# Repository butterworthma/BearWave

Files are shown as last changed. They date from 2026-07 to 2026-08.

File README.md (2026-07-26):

# BearWave

This repository collects the implementation artifacts for the BearWave system.

## Contents

- `control-node/` - Raspberry Pi control-node dashboard, JS8Call/SparkSDR/QSSTV helper configuration, image watcher, startup services, and setup documentation.
- `remote-node/` - Raspberry Pi Zero remote-node application, boot-cycle service, SSTV capture/encode/transmit scripts, ESP32 supervisor code, and the remote-node hardware design material.

The paper source has deliberately been moved out to `BearWave_Papers` so this repository can remain focused on the deployable system code, hardware files, and operator setup notes.

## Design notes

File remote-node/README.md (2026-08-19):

# BearWave Remote Node

This repository contains the current BearWave remote-node software and setup material.

The remote node is the low-power Raspberry Pi and ESP32/Heltec field unit. The ESP32 supervises power, trap inputs, GPS/RTC time, battery state, and deep sleep. The Raspberry Pi boots only during a wake cycle, sends BearWave messages through JS8Call, optionally sends an SSTV image after an acknowledged alarm, asks the ESP32 to shut it down, and then the ESP32 removes the Pi/radio power rail.

The reliable part of BearWave remains the JS8Call alarm and ACK path. The SSTV image is an optional best-effort extension. A missed or undecoded image must not be treated as a missed alarm.

## Repository Layout

```text
remote-pi/
  app/                 Current Raspberry Pi Python application
  scripts/             Boot-cycle, ESP32 UART, JS8Call, and SSTV TX scripts
  systemd/             bearwave-cycle.service template
  requirements.txt     Python packages for the Pi virtual environment

esp32-supervisor/
  BearWave_ESP32_Remote_Node_Supervisor/
    BearWave_ESP32_Remote_Node_Supervisor.ino
  README.md

docs/
  live-pi-setup-check.md
```

## Live Deployment Model

Tested live path on the remote Pi:

```text
/home/mark/bearwave
```

Main live systemd service:

```text
/etc/systemd/system/bearwave-cycle.service
```

Main service target:

```text
graphical.target
```

The service runs as root because it sets system time, launches JS8Call for the `mark` user, communicates with `/dev/serial0`, and halts the Pi at the end of the wake cycle. If a monitor is connected, JS8Call uses the real desktop display; when the field node is headless, the boot script starts a small Xvfb virtual display so JS8Call can still run unattended.

## Wake Cycle Summary

1. ESP32 wakes from timer or event.
2. ESP32 checks the latched 5 V and 12 V rail feedback lines and forces both rails OFF so each cycle starts from a known state.
3. ESP32 refreshes GPS/RTC state, then pulses the 5 V latch on and pulses the 12 V latch on.
4. Raspberry Pi boots into the graphical target.
5. `bearwave-cycle.service` runs `remote-pi/scripts/bearwave_boot_cycle.sh`.
6. The boot script waits for the ESP32 UART at `/dev/serial0`.
7. The boot script waits for the QDX CAT/audio device at `/dev/ttyACM0` before launching JS8Call.
8. The Pi asks the ESP32 for UTC time with `TIME?`.
9. The Pi starts JS8Call on the physical display, or under Xvfb when headless.
10. The Pi waits for the JS8Call TCP API on `127.0.0.1:2442`, then sets JS8Call to 7.078 MHz.
11. The Python app in `remote-pi/app/` sends heartbeat, trap alarm, low-battery, or pending critical messages.
12. The Pi waits for the control-node ACK.
13. If an alarm is acknowledged and SSTV is enabled, the Pi captures, encodes, and transmits one SSTV image.
14. The Pi sends `EVENT_ACKED,<type>` for delivered critical events.
15. The Pi sends `SHUTDOWN` to the ESP32 and halts Linux.
16. ESP32 waits for Linux shutdown, pulses the 12 V latch off, pulses the 5 V latch off, turns the OLED off, and sleeps until the next wake.

## Current SSTV Extension

The SSTV extension is intentionally thin and isolated from the alarm path:

- `remote-pi/app/sstv_image.py` handles image capture, resize/prepare, SSTV WAV encoding, optional JS8Call stop, and transmit command orchestration.
- `remote-pi/scripts/sstv_transmit_qdx.sh` keys the QDX with `rigctl`, plays the generated WAV with `aplay`, and always attempts to release PTT on exit.
- `remote-pi/scripts/bearwave_boot_cycle.sh` passes SSTV configuration into the Python app through environment variables.

Current live defaults from the Pi:

```bash
BEARWAVE_SSTV_ENABLED=1
BEARWAVE_SSTV_DRY_RUN=0
BEARWAVE_SSTV_REPEAT_COUNT=1
BEARWAVE_SSTV_MODE=ScottieS1
BEARWAVE_SSTV_TX_GAIN=1.0
BEARWAVE_SSTV_WORK_DIR=/home/mark/bearwave/sstv
```

Image capture:

```bash
rpicam-still -o {image} --width 1280 --height 960 --timeout 1000 --nopreview
```

Encoding:

```bash
/home/mark/bearwave/.venv/bin/python -m pysstv --mode {mode} {prepared} {wav}
```

Transmit:

```bash
/home/mark/bearwave/scripts/sstv_transmit_qdx.sh {wav}
```

The control node receives this image using QSSTV and displays any decoded image as a clickable thumbnail. Image reception is not guaranteed.

## Raspberry Pi Install

Start from Raspberry Pi OS with a desktop environment. The live node uses user `mark`.

Install system packages:

```bash
sudo apt update
sudo apt install -y git python3 python3-venv python3-pip js8call rpicam-apps ffmpeg alsa-utils libhamlib-utils lxterminal xvfb
```

Clone the repository:

```bash
cd /home/mark
git clone https://github.com/butterworthma/BearWave.git BearWave
mkdir -p /home/mark/bearwave
```

Install the active remote Pi files:

```bash
cp -r /home/mark/BearWave/remote-node/remote-pi/app /home/mark/bearwave/
cp -r /home/mark/BearWave/remote-node/remote-pi/scripts /home/mark/bearwave/
mkdir -p /home/mark/bearwave/logs /home/mark/bearwave/state /home/mark/bearwave/sstv
chmod +x /home/mark/bearwave/scripts/*.sh
chmod +x /home/mark/bearwave/scripts/*.py
```

Create the Python virtual environment:

```bash
cd /home/mark/bearwave
python3 -m venv .venv
. .venv/bin/activate
pip install --upgrade pip
pip install -r /home/mark/BearWave/remote-node/remote-pi/requirements.txt
```

Install the systemd service:

```bash
sudo cp /home/mark/BearWave/remote-node/remote-pi/systemd/bearwave-cycle.service /etc/systemd/system/bearwave-cycle.service
sudo systemctl daemon-reload
sudo systemctl enable bearwave-cycle.service
```

Manual start for bench testing:

```bash
sudo systemctl start bearwave-cycle.service
```

Check status and logs:

```bash
systemctl status bearwave-cycle.service --no-pager -l
journalctl -u bearwave-cycle.service -f
tail -f /home/mark/bearwave/logs/boot_cycle.log
```

## JS8Call Setup

Before unattended testing, start JS8Call manually once and confirm:

- Station callsign is configured.
- TCP API and TCP request acceptance are enabled on `127.0.0.1:2442`.
- The QDX/radio audio device is selected.
- CAT/PTT works from JS8Call.
- The saved desktop profile starts correctly from `/usr/share/applications/js8call.desktop`.

The boot script launches JS8Call using the desktop launcher when a physical display is available, because that path reproduced the saved audio/radio profile reliably during bench testing. If no monitor is connected, it starts `Xvfb` on display `:99` and launches `/usr/bin/js8call` directly in that virtual display. This keeps the Pi Zero 2 W remote node usable as a fully headless field unit.

## QDX SSTV Transmit Setup

Confirm QDX audio and CAT/PTT:

```bash
aplay -l
rigctl -m 2052 -r /dev/ttyACM0 -s 4800 T 0
```

Live tested playback device:

```text
plughw:CARD=Transceiver,DEV=0
```

The transmit helper defaults are:

```bash
BEARWAVE_SSTV_RIG_MODEL=2052
BEARWAVE_SSTV_RIG_DEVICE=/dev/ttyACM0
BEARWAVE_SSTV_RIG_SPEED=4800
BEARWAVE_SSTV_AUDIO_DEVICE=plughw:CARD=Transceiver,DEV=0
BEARWAVE_SSTV_PTT_SETTLE_S=0.5
BEARWAVE_SSTV_TX_GAIN=1.0
```

## ESP32 Supervisor

The ESP32 firmware is stored as a normal Arduino sketch folder:

```text
esp32-supervisor/BearWave_ESP32_Remote_Node_Supervisor/BearWave_ESP32_Remote_Node_Supervisor.ino
```

It controls:

- 5 V Pi rail through the PCB V2 latch pulse on GPIO 7.
- 12 V QDX/radio/ATU rail through the PCB V2 latch pulse on GPIO 38.
- Active-low 5 V and 12 V rail feedback on GPIO 47 and GPIO 48.
- Trap inputs.
- Battery sensing.
- GPS/RTC time.
- OLED diagnostics.
- Pi UART command interface.
- Deep sleep and GPIO hold.

See `esp32-supervisor/README.md` for the pin map, UART protocol, OLED diagnostics, and sleep/wake sequence.

## Important Design Notes

- The ESP32 is the hardware authority.
- The Pi is the radio/application authority.
- The JS8Call alarm message and ACK are the reliable low-power messaging mechanism.
- SSTV is secondary evidence after an alarm and is best effort.
- Failed critical messages are preserved by the Pi app and retried on later boots.
- Routine heartbeats are not stored for retry.
- The control node must not assume an image will always be received.

## Validation Checklist

On the remote Pi:

```bash
test -x /home/mark/bearwave/scripts/bearwave_boot_cycle.sh
test -x /home/mark/bearwave/scripts/sstv_transmit_qdx.sh
/home/mark/bearwave/.venv/bin/python -m py_compile /home/mark/bearwave/app/*.py
/home/mark/bearwave/.venv/bin/python - <<'PY'
import serial
import PIL
import pysstv
print("remote Python dependencies OK")
PY
command -v rpicam-still
command -v aplay
command -v ffmpeg
command -v rigctl
command -v js8call
command -v Xvfb
```

Live check on 2026-07-26 found:

- `rpicam-still` present.
- `aplay` present.
- `ffmpeg` present.
- `js8call` present.
- Python modules `serial`, `PIL`, and `pysstv` present.
- QDX playback device visible as `CARD=Transceiver`.
- `convert` was not present, which is acceptable because the current SSTV path uses Pillow rather than ImageMagick.

## Legacy Note

This repository previously contained a generic headless JS8Call/noVNC setup script. The live BearWave remote node now uses a different architecture: graphical JS8Call launched by the boot-cycle service, ESP32-supervised power, and a Pi app under `/home/mark/bearwave/app`. The old noVNC installer has therefore been removed from the active setup path.

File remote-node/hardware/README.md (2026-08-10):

# BearWave Hardware - Final Board Design



## 📋 Overview

This repository contains the complete hardware documentation for the **BearWave** NVIS (Near Vertical Incidence Skywave) communication system designed for remote wildlife monitoring in the Borneo rainforest. The board integrates a Raspberry Pi Zero 2 W, Heltec V3.2 ESP32 module, GPS, RTC, power management, and radio interfaces for reliable long-range communication in challenging environments.

**GitHub Repository:** [https://github.com/butterworthma/Hardware](https://github.com/butterworthma/Hardware)

## 🎯 Project Purpose

The BearWave hardware platform enables remote wildlife monitoring at the Danau Girang Field Centre (DGFC), Malaysia, providing reliable NVIS communication capabilities for conservation applications in tropical rainforest environments.

## 🖼️ Final Board Design

### Top View - Complete Assembly
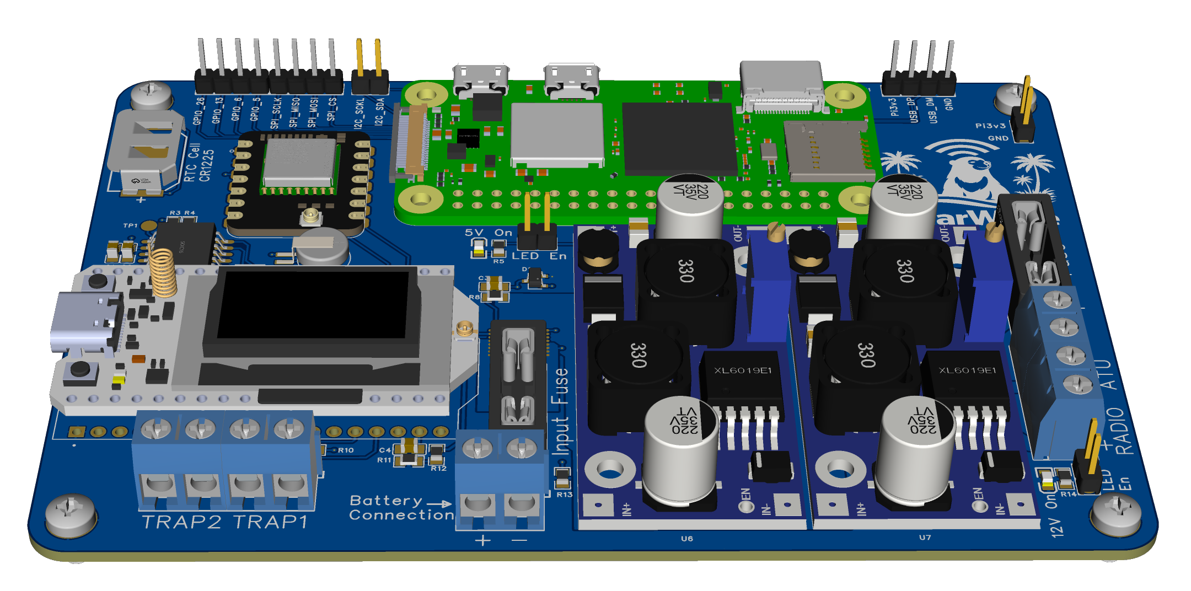
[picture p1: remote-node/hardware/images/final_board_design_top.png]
Final Board Design


The main board features:
- **Blue PCB** with rounded corners (professional manufacturing)
- **Green Raspberry Pi Zero 2 W** daughterboard mounted on standoffs
- **BearWave branding** with logo (bear on island with palm trees and radio waves)
- **Comprehensive I/O** for sensors, radio, and power management

### 3D Rendering View
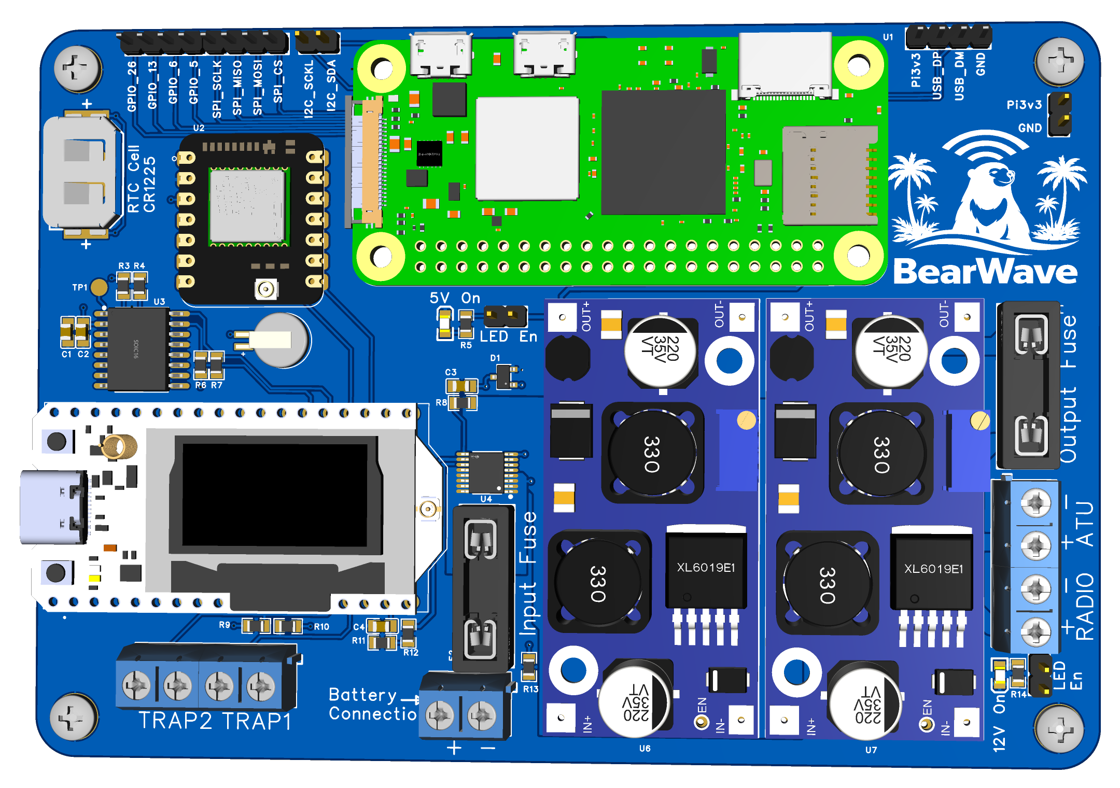
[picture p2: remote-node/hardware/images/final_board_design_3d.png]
3D Board Design


## 🔌 Key Components

### 1. Raspberry Pi Zero 2 W Module (Top Center)
- **Location**: Green daughterboard mounted horizontally on main blue PCB
- **Features**:
  - Dual micro-USB ports (power and data)
  - Mini-HDMI port for display output
  - Micro-SD card slot for operating system storage
  - 40-pin GPIO header connecting to main board
  - Mounted on standoffs for proper clearance

### 2. Heltec V3.2 ESP32 Module
- **Function**: WiFi/Bluetooth connectivity and additional processing
- **Integration**: Connected via UART and I2C to Raspberry Pi
- **Features**: Built-in display driver, GPS interface, power management control

### 3. Real-Time Clock (RTC) Module (Top Left)
- **Component**: DS3231M+ RTC chip with CR1225 coin cell backup
- **Location**: Top-left section of board
- **Features**:
  - Battery-backed timekeeping (CR1225 cell)
  - I2C communication interface
  - Interrupt output for wake-up functionality
  - High accuracy (±2ppm from -40°C to +85°C)

### 4. GPS Module (Middle Section)
- **Function**: Precise location and time synchronization
- **Features**:
  - Battery backup for hot-start capability
  - UART communication (GPS_TX, GPS_RX)
  - Wake-up functionality for power management

### 5. Power Management System (Middle Section)
- **Input Protection**:
  - Fused main battery input (5A fuse)
  - Reverse polarity protection (LTC4358CFE ideal diode controller)
  - Max continuous current: 5A
  
- **Voltage Regulation**:
  - **5V Boost Converter** (XL6019E1): Powers Raspberry Pi and peripherals
  - **12V Boost Converter** (XL6019E1): Powers radio and ATU systems
  - **3.3V Regulation**: For low-power components
  
- **Indicators**:
  - LED indicators for 5V and 12V power status
  - Enable/disable jumpers for power control

### 6. I/O Connectors

#### GPIO Headers (Top Left)
- **GPIO Pins**: GPIO_26, GPIO_13, GPIO_6, GPIO_5
- **SPI Interface**: SCLK, MISO, MOSI, CS
- **I2C Interface**: SCLK, SDA
- **Power**: Pi3V3, GND

#### Screw Terminals
- **Battery Connection**: Main power input (+/-)
- **RADIO**: Radio module power and control (+/-)
- **ATU**: Antenna Tuning Unit connections (+/-)
- **TRAP1/TRAP2**: External sensor/trap connections
- **Input/Output**: Power distribution terminals (IN+/IN-, OUT+/OUT-)

### 7. Display Module (Bottom Left)
- **Type**: OLED or LCD display module
- **Connection**: USB-C interface
- **Function**: System status and data visualization

## 📐 Board Specifications

- **PCB Color**: Blue (standard FR4)
- **Shape**: Rectangular with rounded corners
- **Mounting**: Standoffs for Raspberry Pi Zero 2 W
- **Silkscreen**: White text and component labels
- **Finish**: Professional HASL or ENIG finish

## Enclosure and Printed Carrier

The remote-node electronics are mounted in a 3D-printed internal carrier designed to fit inside a rugged Nanuk 905 protective case. The carrier provides a labelled top/front panel, hardware mounting features, battery retention, ATU/QDX retention features, and service access points for field assembly and inspection.

The current enclosure design includes a Tracer 22 Ah battery, model `BP2548`, mounted as the 12 V battery within the case.

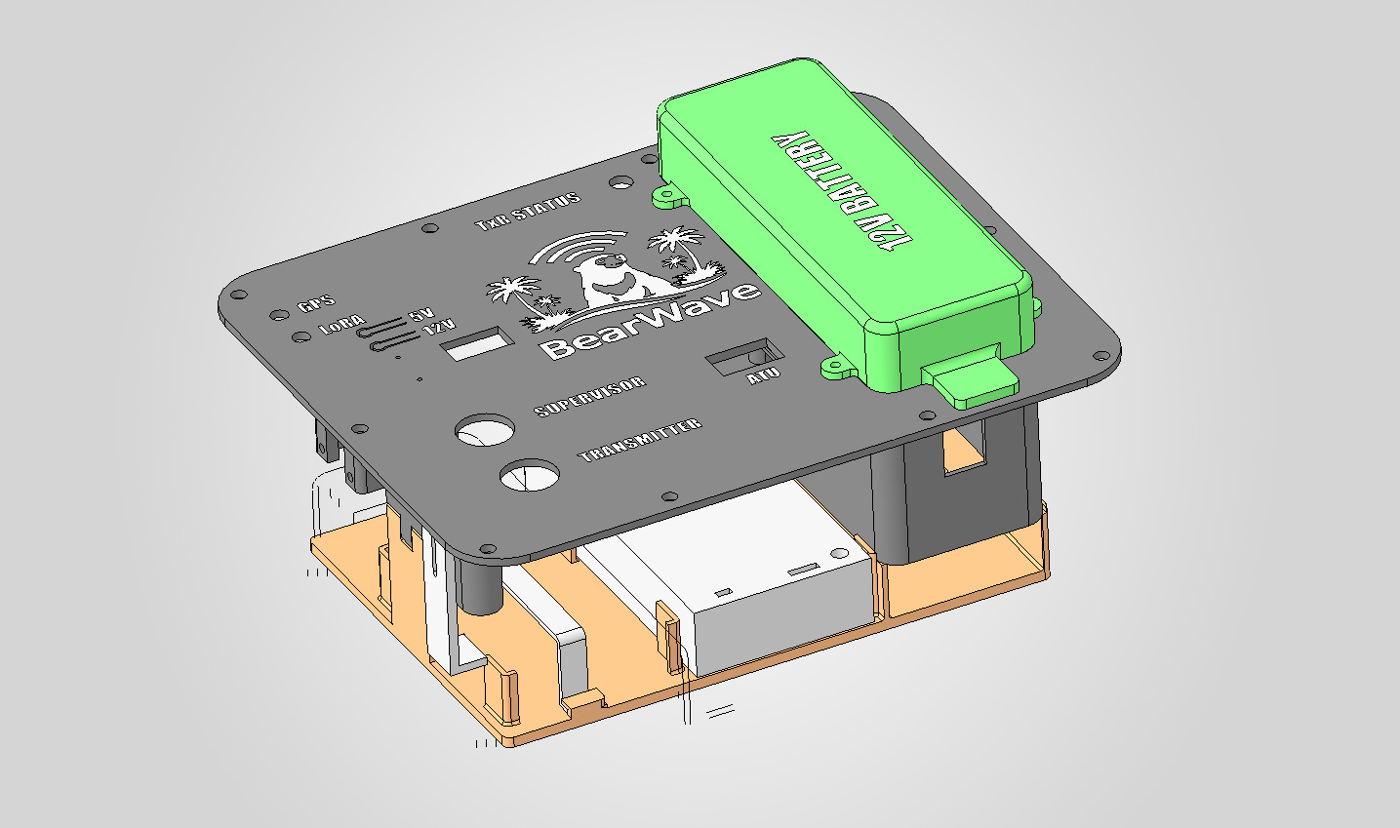
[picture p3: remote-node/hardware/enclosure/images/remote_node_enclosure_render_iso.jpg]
BearWave remote node enclosure internal carrier render


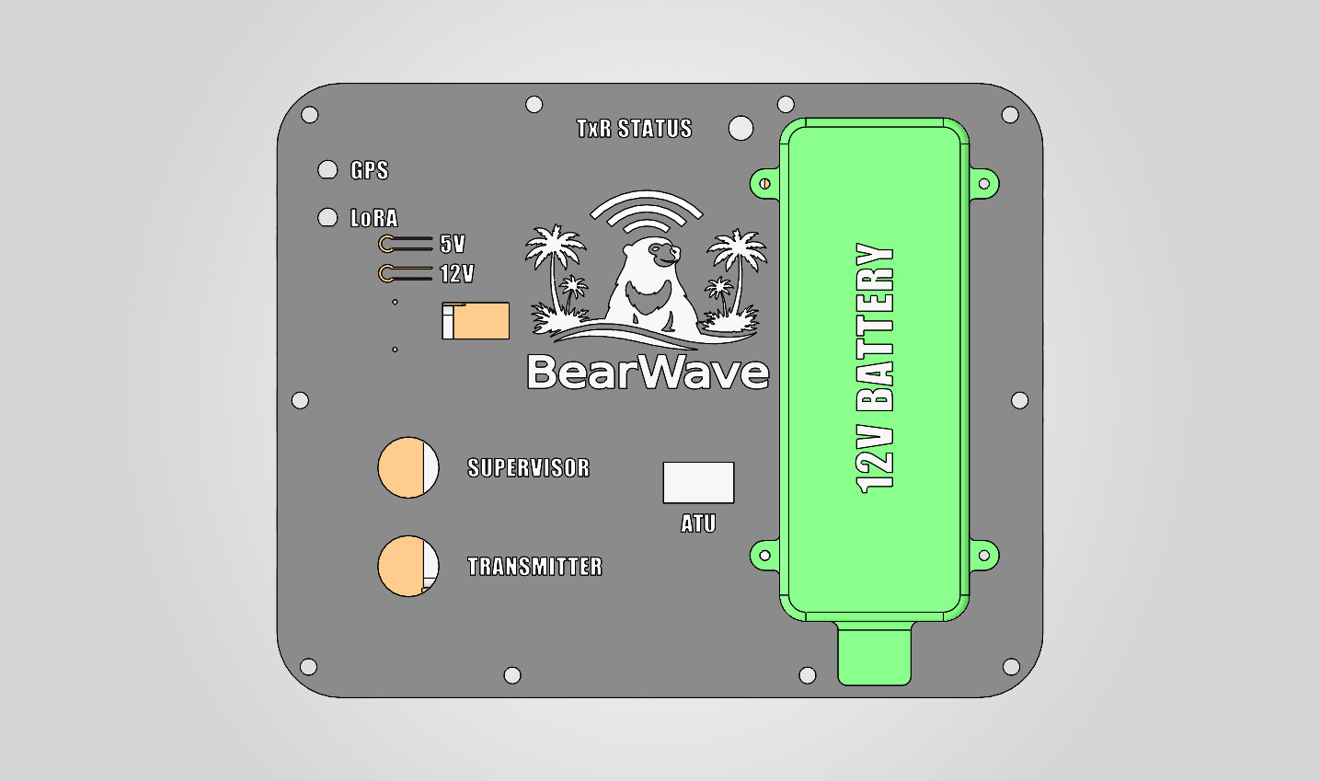
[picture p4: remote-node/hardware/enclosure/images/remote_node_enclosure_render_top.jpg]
BearWave remote node enclosure top panel render


Printable files and reference renders are documented in:

```text
enclosure/
  README.md
  3mf/
  images/
```

See [enclosure/README.md](enclosure/README.md) for the part list, battery note, render images, and assembly notes.

## 🔧 Technical Features

### Communication Interfaces
- **SPI**: High-speed serial communication
- **I2C**: Multi-device bus communication
- **UART**: Serial communication for GPS and debugging
- **USB**: Data transfer and power

### Power Management
- **Input Range**: Compatible with various battery voltages
- **Output Voltages**: 3.3V, 5V, 12V
- **Efficiency**: Boost converters for optimal power usage
- **Protection**: Fuses and reverse polarity protection

### Environmental Considerations
- **Operating Temperature**: Designed for tropical environments
- **Humidity Protection**: Conformal coating compatible
- **Durability**: Professional PCB manufacturing standards

## 📦 Bill of Materials (BOM)

See [BOM Documentation](docs/BOM_Board1_Schematic1_2026-01-05.md) for complete component list.

**Key Components:**
- Raspberry Pi Zero 2 W
- Heltec V3.2 ESP32 Module
- DS3231M+ RTC with CR1225 battery
- XL6019E1 Boost Converters (x2)
- LTC4358CFE Reverse Polarity Protection
- GPS Module with battery backup
- Various passive components (resistors, capacitors, inductors)

## 📄 Documentation

- **[Detailed Board Annotations](docs/board_annotations.md)** - Complete component-by-component breakdown
- **[Schematic Documentation](docs/schematic.md)** - Circuit design details
- **[BOM List](docs/BOM_Board1_Schematic1_2026-01-05.md)** - Complete bill of materials
- **[Assembly Guide](docs/assembly.md)** - Step-by-step assembly instructions

## 🔗 Related Projects

- **Software Repository**: [BearWave-Paper2](https://github.com/butterworthma/BearWave-Paper2)
- **Research Context**: NVIS communication for wildlife monitoring

## 📞 Support

For hardware questions or issues:
- Open an issue on [GitHub](https://github.com/butterworthma/Hardware/issues)
- Refer to documentation in the `docs/` directory

## 📄 License

[Specify your license here]

## 🙏 Acknowledgments

Designed for remote wildlife monitoring research at Danau Girang Field Centre (DGFC), Malaysia, as part of PhD research at Cardiff University.

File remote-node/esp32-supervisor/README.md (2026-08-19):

# BearWave ESP32 Remote-Node Supervisor

This repository contains the ESP32/Heltec supervisor firmware for the BearWave remote node. The ESP32 acts as the hardware authority for the node: it controls the Raspberry Pi and radio power rails, maintains GPS/RTC time, exposes node state to the Pi over UART, monitors alarm inputs, accepts shutdown signalling from the Pi, and enters deep sleep between wake cycles.

## Current version

File:

```text
BearWave_ESP32_Remote_Node_Supervisor/BearWave_ESP32_Remote_Node_Supervisor.ino
```

This version targets BearWave PCB V2, where the 5 V Raspberry Pi rail and 12 V radio/ATU rail are controlled separately through external flip-flop latch circuits.

## Hardware model

BearWave PCB V2 separates the high-power rails:

- 5 V rail for the Raspberry Pi Zero 2 W
- 12 V rail for the QDX/radio/ATU path

Each rail has:

- a pulse input driven briefly HIGH by the ESP32
- a rail-present status input read by the ESP32

On the current PCB V2 bench unit, the latch inputs respond to a short driven-HIGH pulse on the Heltec GPIO pins. The firmware keeps the pulse outputs LOW when idle, drives them HIGH for the configured pulse width, then returns them LOW. Both `5VOK` and `12VOK` are active-low rail-present inputs, so the firmware enables ESP32 internal pull-ups: rail OFF reads HIGH and rail ON reads LOW.

The ESP32 itself must remain powered from an always-on supply, for example the Heltec external battery path or an independent always-on regulator. The latched 5 V and 12 V rails should only control the higher-power Pi and radio/ATU subsystems.

## Why GPIO hold is no longer used

The previous prototype held GPIO 33 during ESP32 deep sleep because it directly controlled a single active-low rail enable. PCB V2 moves this responsibility into external latch hardware. The ESP32 now sends a momentary HIGH pulse and reads back the rail state. The latch, not the ESP32 GPIO drive state, preserves power state during deep sleep.

## Normal operating sequence

1. ESP32 wakes.
2. ESP32 configures latch pulse pins as LOW idle outputs and rail status pins as pulled-up inputs.
3. ESP32 shows reset/wake diagnostics on the OLED.
4. ESP32 forces the 12 V and 5 V rails OFF, then holds them off briefly for visible bench confirmation.
5. ESP32 starts the RTC, GPS, OLED and Pi UART services.
6. ESP32 attempts to refresh RTC time from GPS.
7. ESP32 turns on the 5 V rail, then the 12 V rail, using latch pulses and status feedback.
8. Raspberry Pi boots and asks the ESP32 for time and state over UART.
9. Raspberry Pi runs JS8Call and the BearWave remote-node Python application.
10. Raspberry Pi sends the BearWave heartbeat or alarm message.
11. Raspberry Pi waits for the control-node acknowledgement.
12. Raspberry Pi sends `EVENT_ACKED,<type>` if a critical event was delivered.
13. Raspberry Pi sends `SHUTDOWN` to the ESP32.
14. ESP32 replies `OK,SHUTDOWN_RECEIVED`.
15. ESP32 waits 50 seconds to allow Linux shutdown.
16. ESP32 turns off the 12 V rail, then the 5 V rail, using latch pulses and status feedback.
17. ESP32 arms deep-sleep wake sources for the timer and both active-low trap inputs.
18. ESP32 isolates the Pi UART pins, turns the OLED off, and enters deep sleep.
19. ESP32 wakes by timer, or immediately if Trap 1 on GPIO5 or Trap 2 on GPIO4 pulls low, then repeats.

## UART command interface

The Raspberry Pi communicates with the ESP32 over a line-based UART protocol.

### `PING`

Response:

```text
PONG
```

### `STATUS?`

Response:

```text
OK,BEARWAVE_RTC_GPS_EVENTS
```

### `TIME?`

Responses:

```text
TIME,YYYY-MM-DDTHH:MM:SSZ
ERR,RTC_READ
ERR,RTC_INVALID
```

### `BAT?`

Response:

```text
BAT,<voltage>,<percent>
```

### `COORD?`

Responses:

```text
COORD,<lat>,<lon>
COORD,INVALID
```

### `EVENT?`

Responses:

```text
EVENT,NONE
EVENT,TRAP
EVENT,LOW_BAT
EVENT,TRAP+LOW_BAT
```

### `EVENT_RAW?`

Response:

```text
RAW,<trap1>,<trap2>,<trapLatched>,<trapReported>,<lowBatActive>,<lowBatReported>
```

### `EVENT_ACKED,TRAP`

Response:

```text
OK,EVENT_ACKED,TRAP
```

### `EVENT_ACKED,LOW_BAT`

Response:

```text
OK,EVENT_ACKED,LOW_BAT
```

### `EVENT_ACKED,ALL`

Response:

```text
OK,EVENT_ACKED,ALL
```

### `SHUTDOWN`

Response:

```text
OK,SHUTDOWN_RECEIVED
```

After this command, the ESP32 starts the delayed power-cut and deep-sleep sequence.

## OLED diagnostics

USB serial should not be connected during full power testing because USB 5 V can back-feed the Raspberry Pi. The OLED is therefore used as the primary diagnostic console.

At boot, the OLED shows:

```text
Last stage:<stage>
Boot:<count>
Reset:<reason>
Wake:<reason>
Rail:<5ON/5OFF>/<12ON/12OFF>
```

Healthy sleep/wake behaviour should show:

```text
Reset:DEEPSLEEP
Wake:TIMER
```

If the ESP32 is losing power, the display is more likely to show:

```text
Reset:POWERON
Wake:UNDEFINED
```

If the ESP32 is browning out, it may show:

```text
Reset:BROWNOUT
Wake:UNDEFINED
```

## Shutdown stage values

The sketch stores the last shutdown stage in RTC memory.

```text
0 = Pi sent SHUTDOWN and ESP32 accepted it
1 = ESP32 started rail cut sequence
2 = 12 V and 5 V rails switched off
3 = preparing for sleep
4 = Pi UART pins isolated
5 = deep sleep setup started
6 = OLED off and deep sleep setup started
99 = code continued after esp_deep_sleep_start(), which should not happen
```

A successful diagnostic run should usually show:

```text
Last stage:6
Reset:DEEPSLEEP
Wake:TIMER
Rail:5OFF/12OFF
```

## Timing settings

The shutdown delay is currently:

```cpp
const unsigned long PI_POWER_CUT_DELAY_MS = 50000UL;
```

This gives the Raspberry Pi 50 seconds to halt cleanly before power is removed.

The current diagnostic wake interval is:

```cpp
const uint64_t WAKE_INTERVAL_US = 5ULL * 60ULL * 1000000ULL;
```

For a 15-minute test cycle, change it to:

```cpp
const uint64_t WAKE_INTERVAL_US = 15ULL * 60ULL * 1000000ULL;
```

## Pin summary

| Function | GPIO |
|---|---:|
| 5 V latch pulse, driven HIGH briefly | 7 |
| 12 V latch pulse, driven HIGH briefly | 38 |
| 5 V rail-present status, active low | 47 |
| 12 V rail-present status, active low | 48 |
| Pi UART RX from Pi TX | 33 |
| Pi UART TX to Pi RX | 34 |
| RTC SDA | 40 |
| RTC SCL | 39 |
| RTC interrupt | 6 |
| GPS RX | 41 |
| GPS TX | 42 |
| GPS/VEXT control | 36 |
| Battery ADC | 2 |
| Trap input 1 | 5 |
| Trap input 2 | 4 |

## Integration with BearWave Pi software

The Raspberry Pi should:

1. Boot when the ESP32 confirms the 5 V latch is on.
2. Read ESP32 time using `TIME?`.
3. Set Linux UTC time.
4. Start JS8Call.
5. Set JS8Call to 7.078 MHz.
6. Run the BearWave remote-node Python application.
7. Send `EVENT_ACKED,<type>` after successful critical alarm delivery.
8. Send `SHUTDOWN` before halting.

The ESP32 then turns off the 12 V and 5 V latches and sleeps.

## Notes for deployment

- Keep the ESP32 on an always-on supply.
- The 5 V and 12 V rails should be switched through the PCB V2 latch pulse inputs only.
- Avoid USB serial during full power testing because USB can back-feed the Pi.
- Use the OLED diagnostic values to confirm reset/wake cause.
- Once the behaviour is proven, set the wake interval to the required field-test interval.

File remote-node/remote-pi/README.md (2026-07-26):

# Remote Pi Software

This folder contains the Raspberry Pi side of the BearWave remote node.

`app/` is the current Python application copied from the live remote Pi.

`scripts/` contains the boot-cycle and integration scripts:

- `bearwave_boot_cycle.sh` is launched by systemd at boot.
- `esp32_set_time.py` reads `TIME?` from the ESP32 and sets Linux UTC time.
- `js8_prepare.py` configures JS8Call over its TCP API.
- `esp32_shutdown_request.py` sends the fallback `SHUTDOWN` command.
- `sstv_transmit_qdx.sh` keys the QDX and plays the encoded SSTV WAV.

`systemd/` contains the service template for `/etc/systemd/system/bearwave-cycle.service`.

Install the Python dependencies into `/home/mark/bearwave/.venv`:

```bash
pip install -r remote-pi/requirements.txt
```

The SSTV path uses `Pillow` and `PySSTV`; ImageMagick `convert` is not required.

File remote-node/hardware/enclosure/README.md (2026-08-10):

# BearWave Remote Node Enclosure

This folder contains the 3D-printable enclosure and internal carrier parts for the BearWave remote node. The printed frame is designed to hold the remote-node hardware stack inside a rugged Nanuk 905 protective case.

The enclosure is intended to organise and protect the main electronics rather than replace the outer case. The Nanuk 905 provides the impact-resistant field housing, while these printed parts locate the electronics, battery, connectors, controls, and service labels so that the node can be assembled and inspected consistently.

## Renders

### Internal Carrier Layout

BearWave remote node enclosure internal carrier render

### Top Panel Layout

BearWave remote node enclosure top panel render

## Battery

The current case design includes a Tracer 22 Ah battery, model `BP2548`. The battery is shown in the render as the green 12 V battery block and is retained by the printed battery cover and clip parts.

## Files

The printable files are stored in [`3mf/`](3mf/):

| File | Purpose |
|---|---|
| `BasePlate.3MF` | Main lower carrier plate for the internal hardware frame. |
| `FrontPanel.3MF` | Labelled top/front panel with openings for indicators, switches, ATU access, and BearWave branding. |
| `BatteryCover.3MF` | Cover and locating feature for the Tracer BP2548 12 V battery. |
| `BatteryClip.3MF` | Additional battery retention clip. |
| `atu100Cover.3MF` | Cover for the modified ATU100 section. |
| `QDXClamp.3MF` | Clamp for retaining the QDX transceiver. |
| `LidCover3MF.3MF` | Internal lid cover part. |
| `SMAnutspinner.3MF` | Printed tool for tightening SMA nuts during assembly. |

The reference renders displayed above are stored in [`images/`](images/) so they can be used by this README and reused in the paper/source documentation.

## Assembly Notes

- Print the parts in a material suitable for the intended thermal and humidity environment.
- Trial-fit the printed carrier inside the Nanuk 905 before mounting electronics.
- Verify clearance for the Tracer BP2548 battery, QDX, ATU100, Raspberry Pi, ESP32 supervisor, wiring, switches, and external connectors.
- Check that labels remain visible after installation so field users can distinguish supervisor power, transmitter power, GPS/LoRa indicators, rail status, and antenna/tuner access points.
- Confirm that wiring has strain relief and that cable exits through the Nanuk case preserve the required weather resistance.

The enclosure is part of the reproducible remote-node hardware release. It should be treated as a field-serviceable mechanical design: sites may need to adapt the connector exits, mounting holes, or label positions to suit local deployment practice.

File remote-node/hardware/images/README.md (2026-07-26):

# Images Directory

## Required Images

Please place the following images in this directory:

### 1. Final Board Design - Top View
- **Filename**: `final_board_design_top.png` (or `.jpg`)
- **Description**: Top-down view of the complete BearWave board assembly
- **Content**: Blue PCB with green Raspberry Pi Zero 2 W, all components visible

### 2. Final Board Design - 3D View
- **Filename**: `final_board_design_3d.png` (or `.jpg`)
- **Description**: 3D rendering of the board showing component heights and layout
- **Content**: High-angle 3D view of the assembled board

### 3. PCB Layout - Top View
- **Filename**: `pcb_layout_top.png` (or `.jpg`)
- **Description**: Top view of the bare PCB before component assembly
- **Content**: Blue PCB with white silkscreen, showing component outlines

### 4. Schematic Diagram
- **Filename**: `schematic_diagram.png` (or `.pdf`)
- **Description**: Complete circuit schematic from EasyEDA
- **Content**: Full schematic showing all components and connections

## Image Specifications

- **Format**: PNG (preferred) or JPG
- **Resolution**: Minimum 1920x1080 for detailed views
- **Quality**: High resolution for component visibility
- **Naming**: Use descriptive filenames with underscores

## Usage

These images are referenced in:
- `README.md` - Main repository documentation
- `docs/board_annotations.md` - Detailed component breakdown
- `docs/schematic.md` - Circuit documentation

## Notes

- Ensure images are properly licensed for public repository
- Optimize file sizes for web viewing while maintaining quality
- Consider creating thumbnails for faster loading

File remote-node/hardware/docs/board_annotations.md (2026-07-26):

# BearWave Board - Detailed Annotations

## Complete Component-by-Component Breakdown

---

## Top View - Complete Assembly

### Top Center Section: Raspberry Pi Zero 2 W Module

**Location**: Green daughterboard mounted horizontally on main blue PCB

**Components Visible:**
- **Main SoC**: Large dark grey rectangular component (CPU/GPU)
- **WiFi/Bluetooth Module**: White rectangular component to the left of SoC
- **SD Card Slot**: White rectangular slot on the right side
- **USB Ports**: Two white micro-USB ports along top edge
  - Power input
  - Data/OTG port
- **Mini-HDMI Port**: White port for display output
- **GPIO Header**: 40-pin header along bottom edge connecting to main board
- **Mounting Holes**: Two circular holes (left and right) for standoffs

**Connections to Main Board:**
- GPIO pins (GPIO2-GPIO27)
- SPI interface (SCLK, MISO, MOSI, CS)
- I2C interface (SDA, SCLK)
- UART (TX, RX)
- USB data lines (DP, DM)
- Power (3.3V, 5V, GND)

---

### Top Left Section: RTC and GPIO Headers

**RTC Module:**
- **Component**: DS3231M+ Real-Time Clock IC (U3, SOIC-16 package)
- **Battery Holder**: White rectangular component labeled "RTC Cell CR1225"
  - Holds CR1225 coin cell for backup power
  - Ensures timekeeping during power loss
- **Supporting Components**:
  - **R3, R4, R6, R7**: 4.7KΩ pull-up resistors (I2C bus)
  - **C1**: 1µF capacitor
  - **C2**: 100nF capacitor
  - **CR1**: 32.768kHz crystal (MY-1225-01-J)

**GPIO Headers:**
- **Pin Labels** (from left to right):
  - GPIO_26
  - GPIO_13
  - GPIO_6
  - GPIO_5
  - SPI_SCLK (SPI Clock)
  - SPI_MISO (SPI Master In Slave Out)
  - SPI_MOSI (SPI Master Out Slave In)
  - SPI_CS (SPI Chip Select)
  - I2C_SCLK (I2C Clock)
  - I2C_SDA (I2C Data)

**Power Connections:**
- **Screw Terminal**: "+" symbol at very top left
- **Pi3V3**: 3.3V power rail
- **GND**: Ground connections

---

### Top Right Section: BearWave Branding and Power/USB Headers

**BearWave Logo:**
- **Design**: White logo featuring:
  - Bear sitting on small island
  - Two palm trees
  - Three white arcs above bear's head (radio waves)
- **Text**: "BearWave" in bold white sans-serif font
- **Location**: Prominently displayed in upper right quadrant

**Power/USB Headers:**
- **Header Set 1** (above logo):
  - Pi3V3 (3.3V power)
  - USB_DP (USB Data Positive)
  - USB_DM (USB Data Minus)
  - GND (Ground)
  
- **Header Set 2** (to the right):
  - Pi3V3 (3.3V power)
  - GND (Ground)

**Screw Terminal:**
- **Location**: Very top right
- **Label**: "+" symbol
- **Function**: Additional power connection point

---

### Middle Section: Power Regulation and Fuses

**Boost Converters:**
- **Inductors**: Four large dark blue circular inductors
  - Each labeled "330" (330µH)
  - Part of boost converter circuits
  - Energy storage for voltage conversion
  
- **ICs**: Four black integrated circuits
  - Two labeled "XL6019E1" (boost converter controllers)
  - **U6**: 5V boost converter
  - **U7**: 12V boost converter
  - High-efficiency switching regulators

**Capacitors:**
- **Electrolytic Capacitors**: White cylinders with black tops
  - Labeled "220 35V VT" (220µF, 35V rating)
  - Power filtering and energy storage
  - Smooth output voltage

**Fuses:**
- **Input Fuse** (F2, left side):
  - Black rectangular component with metal clips
  - Protects against overcurrent on battery input
  - 5A rating (3557-2 type)
  
- **Output Fuse** (F1, right side):
  - Black rectangular component with metal clips
  - Protects 12V output circuit
  - Prevents damage from short circuits

**Indicators and Controls:**
- **LED1**: "5V On" indicator
  - Green LED (HL-PC-2012U97GC-L)
  - Shows 5V power status
  - Current limiting resistor R5 (910Ω)
  
- **LED2**: "12V On" indicator
  - Green LED
  - Shows 12V power status
  - Current limiting resistor R14 (3.6KΩ)
  
- **Jumpers**:
  - "LED En": Enable/disable LED indicators
  - Power control jumpers

**Screw Terminals:**
- **IN+**: Positive input terminal
- **IN-**: Negative input terminal (ground)
- **OUT+**: Positive output terminal
- **OUT-**: Negative output terminal (ground)

**Supporting Components:**
- **D1**: Protection diode (MMBD1205)
- **C3**: 100nF capacitor (filtering)
- **R5, R8**: Current limiting resistors
- **R13**: 100KΩ pull-down resistor for power enable

---

### Bottom Left Section: Display and Battery Connection

**Display Module:**
- **Type**: Large white rectangular module
- **Screen**: Black display area (likely OLED or LCD)
- **Interface**: USB-C port on left side
- **Function**: System status display and data visualization
- **Mounting**: Secured to main board

**Screw Terminal Blocks:**
- **TRAP2/TRAP1**: Blue terminal blocks
  - Connections for external trap sensors
  - Two independent trap monitoring channels
  - Pull-up resistors R9, R10 (47KΩ) for switch inputs

- **Battery Connection**: Blue terminal block
  - Labeled "Battery Connection" (text may be truncated)
  - **+** terminal: Positive battery connection
  - **-** terminal: Negative battery connection (ground)
  - Main power input for entire system

---

### Bottom Right Section: Radio/ATU Connections

**Screw Terminal Block:**
- **RADIO**: Radio module connections
  - **+** terminal: Positive power (12V)
  - **-** terminal: Ground
  
- **ATU**: Antenna Tuning Unit connections
  - **+** terminal: Positive power (12V)
  - **-** terminal: Ground
  - Enables automatic antenna matching for NVIS operation

**Indicators:**
- **LED**: "12V On" indicator
  - Shows 12V power status for radio systems
  
- **Jumper**: "LED En"
  - Enable/disable LED indicator

---

## Power Flow and Distribution

### Input Path:
1. **Battery Connection** (bottom left) → Main battery input
2. **Input Fuse** (F2) → Overcurrent protection
3. **Reverse Polarity Protection** (U4, LTC4358CFE) → Prevents damage from reversed battery
4. **M_BAT_OUT** → Protected battery voltage

### Power Rails:
1. **3.3V Rail**:
   - Powers: RTC, GPS, ESP32, low-power components
   - Derived from main battery via regulator

2. **5V Rail** (Boost Converter U6):
   - Powers: Raspberry Pi Zero 2 W
   - Powers: USB peripherals
   - Inductor: 330µH
   - Output capacitor: 220µF 35V
   - LED indicator: LED1

3. **12V Rail** (Boost Converter U7):
   - Powers: Radio module
   - Powers: ATU (Antenna Tuning Unit)
   - Inductor: 330µH
   - Output capacitor: 220µF 35V
   - Output fuse: F1
   - LED indicator: LED2

---

## Communication Interfaces

### I2C Bus:
- **Devices**: RTC (U3), ESP32, other I2C peripherals
- **Lines**: SDA (data), SCLK (clock)
- **Pull-ups**: R3, R4, R6, R7 (4.7KΩ)
- **Voltage**: 3.3V logic

### SPI Bus:
- **Devices**: High-speed peripherals, displays
- **Lines**: SCLK, MISO, MOSI, CS
- **Voltage**: 3.3V logic

### UART:
- **GPS UART**: GPS_TX, GPS_RX
- **Pi UART**: PIUARTTX, PIUARTRX
- **Function**: Serial communication for GPS and debugging

### USB:
- **Data Lines**: USB_DP, USB_DM
- **Function**: Data transfer, device communication
- **Power**: 5V from boost converter

---

## Safety and Protection Features

1. **Input Fuse** (F2): Protects against overcurrent on battery input
2. **Output Fuse** (F1): Protects 12V output circuit
3. **Reverse Polarity Protection** (U4): Ideal diode controller prevents damage
4. **Voltage Monitoring**: Battery voltage divider (R11, R12) for ADC monitoring
5. **Current Limiting**: Resistors on LED circuits and power paths

---

## Environmental Considerations

- **Operating Temperature**: Designed for tropical environments
- **Humidity**: Conformal coating compatible
- **Durability**: Professional PCB manufacturing
- **Mounting**: Standoffs for proper airflow and isolation

---

## Design Notes

- **PCB Color**: Blue (standard FR4 substrate)
- **Silkscreen**: White text and component labels
- **Finish**: Professional HASL or ENIG (gold) finish
- **Shape**: Rectangular with rounded corners
- **Mounting Holes**: For secure installation in field equipment

---

## Revision Information

- **Design Date**: 2025-11-21
- **Last Update**: 2026-01-03
- **Version**: V1.0
- **Schematic**: Schematic1
- **Board**: Board1

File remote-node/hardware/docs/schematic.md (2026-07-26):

# BearWave Schematic Documentation

## Schematic Overview

**Title**: BearWave  
**Software**: EasyEDA  
**Creation Date**: 2025-11-21  
**Last Update**: 2026-01-03  
**Version**: V1.0  
**Schematic**: Schematic1  
**Board**: Board1  
**Page Size**: A4

---

## Functional Blocks

### 1. Heltec V3.2 ESP32 Module (Top-Left, A1-B1)

**Component**: U5.1 - WIFI_KIT_32_V3_

**Power Connections:**
- **+5V**: 5V power input
- **3V3**: 3.3V power rail
- **GND**: Ground connections

**GPIO Pins:**
- GPIO2 through GPIO27 (extensive I/O capability)

**Communication Interfaces:**
- **PIUARTTX/PIUARTRX**: UART communication with Raspberry Pi
- **RTC_SDA/RTC_SCL**: I2C connection to RTC module
- **GPS_TX/GPS_RX**: UART communication with GPS module
- **USB_DP/USB_DM**: USB data lines
- **ID_SD/ID_SC**: I2C identification lines

**Control Signals:**
- **/ENPSU**: Power supply enable (active low)
- **RTC_INT**: RTC interrupt signal
- **TRAPSWITCH2/TRAPSWITCH1**: Trap sensor inputs
- **MAINBATLVL**: Main battery voltage level (ADC input)

**Design Note**: "Ensure JTAG is disabled" - Security consideration for production deployment

---

### 2. Raspberry Pi Zero 2 W (Top-Right, A3-B6)

**Component**: U1 - RASPBERRY_PI_ZERO_2_W

**Power Connections:**
- **PI3V3**: 3.3V power rail
- **+5V**: 5V power input (from boost converter)
- **GND**: Ground connections

**GPIO Pins:**
- **GPIO2/SDA1** through **GPIO27/GPIO_GEN2**
- Extensive GPIO capability for peripherals

**Communication Interfaces:**
- **USB_DP/USB_DM**: USB data lines
- **I2C_SDA/I2C_SCLK**: I2C bus
- **SPI_MISO/SPI_MOSI/SPI_SCLK/SPI_CS**: SPI bus
- **PIUARTTX/PIUARTRX**: UART communication

**Headers (H1-H9):**
- **H1-H4**: GPIO connections
- **H5-H6**: I2C bus (SDA, SCLK)
- **H7-H9**: SPI bus (MISO, MOSI, SCLK, CS)
- **Power**: Pi3V3 and GND connections

**Pull-up Resistors:**
- **R1, R2**: 4.7KΩ pull-up resistors
  - Connected to PI3V3
  - On I2C lines (SDA, SCLK)
  - Standard I2C bus termination

---

### 3. Fused Main Battery Input and Reverse Polarity Protection (Middle-Left, B1-C2)

**Input Protection Circuit:**

**Fuse (F2):**
- **Type**: 3557-2 fuse holder
- **Location**: Between M_BAT_IN and protection circuit
- **Function**: Overcurrent protection (5A rating)

**Ideal Diode Controller (U4):**
- **Part**: LTC4358CFE#PBF (ADI)
- **Package**: HTSSOP-16
- **Function**: Reverse polarity protection
- **Input**: M_BAT_IN (after fuse)
- **Output**: M_BAT_OUT (protected battery voltage)
- **Max Current**: 5A continuous

**Supporting Components:**
- **D1**: MMBD1205 diode (protection)
- **R8**: 100Ω resistor (current limiting)
- **C3**: 100nF capacitor (filtering)

**Design Note**: "Fused main battery input and reverse polarity protection Max continuous current 5amp"

---

### 4. GPS Module + Battery Backup (Middle-Middle, B3-C4)

**Component**: U2 - GPSModule

**Power Connections:**
- **SWITCHED3V3**: Switched 3.3V power (for power management)
- **GND**: Ground
- **3V3**: Continuous 3.3V power
- **RESET**: Reset signal

**Communication:**
- **Tx**: GPS transmit (connected to GPS_TX)
- **Rx**: GPS receive (connected to GPS_RX)
- **WakeUp**: Wake-up signal for power management

**Battery Backup:**
- **Bat1**: MS621FE_FL11E_1 battery
- **Connection**: Via CN1 connector
- **Function**: Maintains GPS memory for hot-start capability
- **Benefit**: Faster GPS lock times after power cycles

---

### 5. RTC (Real-Time Clock) (Middle-Right, B4-C6)

**Component**: U3 - DS3231M+ (ADI/MAXIM)

**Power Connections:**
- **3V3**: 3.3V power rail
- **VCC**: Primary power supply
- **VBAT**: Battery backup (connected to RTCBAT)

**Timing:**
- **CR1**: 32.768kHz crystal (MY-1225-01-J)
- **Function**: Precise timekeeping reference
- **Accuracy**: ±2ppm from -40°C to +85°C

**Communication:**
- **SCL**: I2C clock (connected to RTC_SCL)
- **SDA**: I2C data (connected to RTC_SDA)
- **Interface**: Standard I2C protocol

**Interrupt:**
- **INT#/SQW**: Interrupt/square wave output
- **Connected to**: RTC_INT
- **Function**: Wake-up signal, periodic interrupts

**Supporting Components:**
- **C1**: 1µF capacitor (power filtering)
- **C2**: 100nF capacitor (decoupling)
- **R3, R4, R6, R7**: 4.7KΩ pull-up resistors (I2C bus)
- **TP1**: Test point for debugging

**Battery Backup:**
- **RTCBAT**: CR1225 coin cell connection
- **Function**: Maintains time during power loss

---

### 6. Trap Switch Inputs (Bottom-Left, D1-E1)

**Input Channels:**
- **TRAPSWITCH2**: Second trap sensor input
- **TRAPSWITCH1**: First trap sensor input

**Pull-up Resistors:**
- **R9**: 4.7KΩ pull-up to 3V3 (TRAPSWITCH2)
- **R10**: 4.7KΩ pull-up to 3V3 (TRAPSWITCH1)

**Connectors:**
- Two 2-pin connectors for external trap sensors
- Active-high logic (pulled high, goes low when triggered)

**Function**: Monitor wildlife trap status remotely

---

### 7. 5V and 12V Buck-Boost Modules (Bottom-Middle-Left, D2-E3)

**5V Boost Converter (U6):**
- **Module**: XL6019 Module
- **Input**: M_BAT_OUT (protected battery voltage)
- **Output**: +5V
- **Function**: Powers Raspberry Pi Zero 2 W and USB peripherals
- **Inductor**: 330µH (external, not in schematic detail)
- **Output Capacitor**: 220µF 35V (filtering)

**Supporting Components:**
- **R5**: 910Ω current limiting resistor
- **LK1**: LED enable jumper
- **LED1**: Power status indicator (5V On)

**12V Boost Converter (U7):**
- **Module**: XL6019 Module
- **Input**: M_BAT_OUT (protected battery voltage)
- **Output**: +12V
- **Function**: Powers radio module and ATU
- **Inductor**: 330µH (external)
- **Output Capacitor**: 220µF 35V (filtering)

**Output Protection:**
- **F1**: 3557-2 fuse on +12V output
- **Function**: Protects radio/ATU circuits from overcurrent

**Supporting Components:**
- **R14**: 3.6KΩ current limiting resistor
- **LK2**: LED enable jumper
- **LED2**: Power status indicator (12V On)

**Power Enable:**
- **/ENPSU**: Power supply enable signal (active low)
- **R13**: 100KΩ pull-down resistor
- **Function**: Allows software control of power supplies

---

### 8. Battery Voltage ADC Divider (Bottom-Middle-Right, D3-E4)

**Voltage Divider Circuit:**
- **R12**: 1MΩ resistor (upper leg)
- **R11**: 250KΩ resistor (lower leg)
- **Input**: M_BAT_OUT (battery voltage)
- **Output**: MAINBATLVL (ADC input to ESP32)

**Calculation:**
- **Divider Ratio**: R11/(R11+R12) = 250K/(250K+1M) = 0.2
- **ADC Range**: 0-3.3V (typical ESP32 ADC)
- **Battery Range**: 0-16.5V (theoretical, practical range depends on battery)

**Supporting Component:**
- **C4**: 100nF capacitor (filtering, reduces noise)

**Function**: Monitor battery voltage for power management and low-battery warnings

---

## Power Distribution Summary

### Input:
- **M_BAT_IN** → Fuse (F2) → Reverse Protection (U4) → **M_BAT_OUT**

### Output Rails:
1. **3.3V**: Direct regulation from M_BAT_OUT
   - Powers: RTC, GPS, ESP32, low-power components

2. **5V**: Boost converter (U6) from M_BAT_OUT
   - Powers: Raspberry Pi Zero 2 W, USB peripherals
   - Indicator: LED1

3. **12V**: Boost converter (U7) from M_BAT_OUT
   - Powers: Radio module, ATU
   - Protected by: Fuse (F1)
   - Indicator: LED2

---

## Communication Bus Summary

### I2C Bus:
- **Devices**: RTC (U3), ESP32, Raspberry Pi
- **Lines**: SDA, SCLK
- **Pull-ups**: R1, R2, R3, R4, R6, R7 (4.7KΩ)
- **Voltage**: 3.3V

### SPI Bus:
- **Devices**: High-speed peripherals
- **Lines**: SCLK, MISO, MOSI, CS
- **Voltage**: 3.3V

### UART:
- **GPS UART**: GPS_TX, GPS_RX (ESP32 ↔ GPS)
- **Pi UART**: PIUARTTX, PIUARTRX (ESP32 ↔ Raspberry Pi)

---

## Design Considerations

1. **Power Efficiency**: Boost converters for optimal battery usage
2. **Protection**: Fuses and reverse polarity protection
3. **Reliability**: Battery backup for RTC and GPS
4. **Monitoring**: Battery voltage and trap status
5. **Flexibility**: Multiple communication interfaces
6. **Field Deployment**: Designed for harsh tropical environments

---

## Revision History

- **2026-01-03**: Updated schematic (V1.0)
- **2025-11-21**: Initial schematic creation

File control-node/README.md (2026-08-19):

# BearWave Control Node

BearWave Control Node is the Raspberry Pi side of the BearWave remote trap monitor. It runs beside SparkSDR, JS8Call, and QSSTV on the control-node Pi and provides a permanent 7 inch dashboard for node status, alarms, received images, event history, and logs.

The reliable part of the system is the low-power JS8Call alarm/heartbeat/ACK path. SSTV image reception is an optional best-effort extension: when the remote node sends an image after an alarm, QSSTV decodes any valid picture it can hear and the dashboard links the latest image to the most recent alarming node.

## Repository Contents

- `src/index.js` starts the Express/Socket.IO dashboard, connects to JS8Call, parses BearWave messages, schedules delayed ACKs, and starts the SSTV image watcher.
- `src/protocol/` parses and encodes compact BearWave protocol payloads.
- `src/js8/` manages the JS8Call TCP API connection, message assembly, and ACK scheduling.
- `src/state/` stores node status, alarm state, heartbeat freshness, telemetry, and linked SSTV thumbnails.
- `src/images/imageStore.js` watches the SSTV inbox and publishes new images to the dashboard.
- `src/ui/public/` contains the touch-screen dashboard.
- `scripts/start_control_desktop.sh` starts SparkSDR, JS8Call, the QSSTV audio router, and Chromium kiosk mode.
- `scripts/start_qsstv_rx.sh` starts QSSTV and repeatedly routes the SparkSDR monitor audio into QSSTV and JS8Call at controlled capture levels.
- `scripts/sstv_rx_loop.sh` is an optional non-GUI recording/decoder loop used during bench testing.
- `scripts/sstv_decode_file.py` decodes a recorded SSTV WAV file using the local SSTV Python environment.
- `systemd/bearwave-sstv-rx.service` is an optional service file for the headless recording/decoder loop.

## Hardware Assumptions

The tested control node used:

- Raspberry Pi with desktop environment and 7 inch display.
- Hermes-Lite SDR connected to the control Pi network.
- USB audio route from SparkSDR monitor audio.
- SparkSDR for SDR receive/control.
- JS8Call for BearWave alarm and heartbeat messages.
- QSSTV for receive-only SSTV image decode.

The exact SDR, audio device names, callsigns, and frequencies are site-specific. Treat the provided defaults as the tested bench configuration, not universal settings.

## Install System Packages

Start from Raspberry Pi OS with a graphical desktop.

```bash
sudo apt update
sudo apt install -y git curl nodejs npm chromium-browser x11-utils pulseaudio-utils ffmpeg python3 python3-venv qsstv js8call wmctrl xdotool gpsd-clients dnsmasq-base
```

Install SparkSDR using the package or installer appropriate for the control-node Pi. Confirm it can connect to the Hermes-Lite before configuring BearWave.

## Clone And Install

```bash
cd /home/mark
git clone https://github.com/butterworthma/ControlNode.git control-node
cd /home/mark/control-node
npm install
mkdir -p logs sstv-images/inbox sstv-audio
cp .env.example .env
```

Edit `.env` for your station:

```bash
nano .env
```

At minimum, set:

- `SIMULATE_JS8=0` for live JS8Call operation.
- `JS8CALL_HOST=127.0.0.1`
- `JS8CALL_PORT=2442`
- `BEARWAVE_REMOTE_CALLSIGN` and per-node callsign overrides if required.
- `BEARWAVE_SSTV_IMAGE_DIR=/home/mark/control-node/sstv-images/inbox`

Do not commit `.env`; it may contain local station details.

## JS8Call Configuration

In JS8Call:

1. Configure the station callsign and radio/audio settings as normal.
2. Enable the TCP API server.
3. Use TCP port `2442` unless you also change `JS8CALL_PORT`.
4. Confirm JS8Call can decode BearWave messages from the remote node.
5. Confirm JS8Call can transmit a directed ACK from the control station.

The control-node software expects BearWave payloads in this form:

```text
BW1|<nodeId>|<type>|<messageId>|<flags>|<data>
```

Example:

```text
BW1|ND01|ALARM|7K|0|B72
```

The ACK is compact and node-specific:

```text
A|ND01|7K
```

## SparkSDR And Audio Routing

SparkSDR should provide the received audio that both JS8Call and QSSTV listen to. In the tested setup, the monitor source was:

```text
alsa_output.usb-C-Media_Electronics_Inc._USB_Audio_Device-00.analog-stereo.monitor
```

Check your own PulseAudio/PipeWire source names with:

```bash
pactl list short sources
pactl list source-outputs
```

If your source name differs, edit `scripts/start_qsstv_rx.sh` and update `MONITOR_SOURCE`, or export the correct value before starting the script.

The tested capture volume after tuning was:

```bash
BEARWAVE_QSSTV_CAPTURE_VOLUME=60%
BEARWAVE_JS8CALL_CAPTURE_VOLUME=60%
```

These values reduce overloading and improve reliable JS8Call decode while keeping SSTV decode usable.

## Dashboard Controls

The 7 inch dashboard is intended to be the permanent operator screen. It is not
just a passive web page:

- The top-left menu opens window controls for minimise, maximise, and close.
  These controls call the local backend, which uses `wmctrl` and `xdotool`
  against the Chromium kiosk window.
- The circular button beside the UTC clock requests a GPS time resync. The
  backend reads GPS time with `gpspipe`; if no GPS is attached or no valid UTC
  fix is available, the dashboard reports that cleanly instead of changing the
  clock.
- Each node image strip has `Ack` and `Clear` controls. `Ack` marks the current
  alarm state as acknowledged in the dashboard state. `Clear` removes that node
  card from the local display state, which is useful after bench tests or after
  a trap visit.
- The bottom tabs switch between Dashboard, Nodes, Alerts, History, Map, and
  Logs. Map is currently reserved for later work; Logs shows the control-node
  application log so a monitor connected to the Pi can show what the system is
  doing without an SSH session.

If GPS time setting is required from the dashboard, allow the dashboard user to
run `date` without a password:

```bash
echo 'mark ALL=(root) NOPASSWD: /usr/bin/date' | sudo tee /etc/sudoers.d/bearwave-gps-time
sudo chmod 440 /etc/sudoers.d/bearwave-gps-time
```

## Standalone Hermes-Lite Ethernet Link

For field deployment, the control-node Pi can keep WLAN available for
maintenance while providing a private DHCP network on its Ethernet port for the
directly connected Hermes-Lite SDR.

The tested private Ethernet plan is:

```text
Pi wlan0: site/admin network, DHCP from normal router
Pi eth0:  192.168.50.1/24 static
Hermes-Lite: 192.168.50.85 from Pi DHCP
Hermes-Lite MAC: 00:1c:c0:a2:13:dd
```

The DHCP configuration is stored in
`config/dnsmasq-hermes-eth0.conf`, and the systemd unit is
`systemd/bearwave-hermes-dhcp.service`.

Install on the control node with:

```bash
sudo apt-get install -y dnsmasq-base
sudo nmcli connection add type ethernet ifname eth0 con-name bearwave-hermes-eth0 ipv4.method manual ipv4.addresses 192.168.50.1/24 ipv4.never-default yes ipv6.method disabled
sudo cp /home/mark/control-node/systemd/bearwave-hermes-dhcp.service /etc/systemd/system/bearwave-hermes-dhcp.service
sudo systemctl daemon-reload
sudo systemctl enable --now bearwave-hermes-dhcp.service
```

SparkSDR's `Last_Session` profile stores the Hermes-Lite by device identity
rather than by the previous WLAN IP address. Once the Hermes-Lite is moved to
the direct Ethernet link and receives `192.168.50.85`, SparkSDR should load the
same Last Session profile against the same radio hardware.

## QSSTV Configuration

QSSTV is used as a receive-only image decoder.

1. Start QSSTV once from the desktop.
2. Configure the input audio device to the SparkSDR monitor audio or the routed PulseAudio source.
3. Configure receive/save output to:

```text
/home/mark/control-node/sstv-images/inbox
```

4. Leave QSSTV listening. It should only save images when it decodes a valid SSTV transmission.

The BearWave dashboard watches this inbox. When a new image appears, it displays a clickable thumbnail and tries to associate it with the most recent alarm within the configured association window.

## Run Manually

Simulator mode is useful before JS8Call and radio software are ready:

```bash
cd /home/mark/control-node
npm run simulate
```

Live mode:

```bash
cd /home/mark/control-node
npm start
```

Open the dashboard:

```text
http://127.0.0.1:3000/
```

Useful diagnostic endpoints:

```text
http://127.0.0.1:3000/api/nodes
http://127.0.0.1:3000/api/events
http://127.0.0.1:3000/api/images
```

## Start The Desktop Stack On Boot

The intended control-node boot behaviour is:

1. Start SparkSDR.
2. Start JS8Call.
3. Start QSSTV and keep the SparkSDR monitor audio routed into QSSTV and JS8Call.
4. Start the BearWave web application.
5. Open Chromium in kiosk mode on the 7 inch dashboard.

One practical setup is to run the Node application as a user service and run the desktop launcher from the graphical user session.

Create a user service for the dashboard:

```bash
mkdir -p ~/.config/systemd/user
nano ~/.config/systemd/user/bearwave-control-node.service
```

Paste:

```ini
[Unit]
Description=BearWave control-node dashboard
After=network-online.target

[Service]
Type=simple
WorkingDirectory=/home/mark/control-node
EnvironmentFile=/home/mark/control-node/.env
ExecStart=/usr/bin/npm start
Restart=always
RestartSec=5

[Install]
WantedBy=default.target
```

Enable it:

```bash
systemctl --user daemon-reload
systemctl --user enable --now bearwave-control-node.service
loginctl enable-linger mark
```

Then add the desktop launcher to the Pi desktop autostart:

```bash
mkdir -p ~/.config/autostart
nano ~/.config/autostart/bearwave-control-desktop.desktop
```

Paste:

```ini
[Desktop Entry]
Type=Application
Name=BearWave Control Desktop
Exec=/home/mark/control-node/scripts/start_control_desktop.sh
Terminal=false
X-GNOME-Autostart-enabled=true
```

Make scripts executable:

```bash
chmod +x /home/mark/control-node/scripts/*.sh
```

The desktop launcher starts Chromium with `--password-store=basic`. This avoids
the graphical keyring unlock prompt that otherwise appears before the dashboard
opens on boot.

Reboot and confirm the dashboard appears automatically:

```bash
sudo reboot
```

## Optional SSTV Recording/Decode Loop

The primary live image path is QSSTV. The optional loop in `scripts/sstv_rx_loop.sh` records overlapping audio chunks with `ffmpeg` and tries to decode them using `scripts/sstv_decode_file.py`.

Set up the Python environment:

```bash
cd /home/mark/control-node
python3 -m venv .venv-sstv
. .venv-sstv/bin/activate
pip install --upgrade pip
pip install PySSTV Pillow
```

Install the service if required:

```bash
mkdir -p ~/.config/systemd/user
cp systemd/bearwave-sstv-rx.service ~/.config/systemd/user/
systemctl --user daemon-reload
systemctl --user enable --now bearwave-sstv-rx.service
```

For the current control-node design, QSSTV is usually the better permanent receiver because it is visual, interactive, and only saves valid decodes.

## Logs

Application events are written to:

```text
/home/mark/control-node/logs/events.log
```

Desktop startup and audio routing logs are written to:

```text
/home/mark/control-node/logs/desktop-start.log
/home/mark/control-node/logs/qsstv-rx.log
```

The dashboard `Logs` tab displays the control-node event log for quick checking when a monitor is attached.

## Validation Checklist

1. Start SparkSDR and confirm the Hermes-Lite waterfall and audio are present.
2. Start JS8Call and confirm it decodes normal JS8 traffic.
3. Run `npm run simulate` and confirm the dashboard loads at `http://127.0.0.1:3000/`.
4. Run `npm start` and confirm the log reports `Connected to JS8Call`.
5. Trigger or simulate a BearWave heartbeat and confirm the node appears on the dashboard.
6. Trigger a BearWave alarm and confirm the dashboard marks the node as alarmed.
7. Confirm the delayed ACK is scheduled and transmitted by JS8Call.
8. Leave QSSTV receiving and send a remote-node SSTV image.
9. Confirm QSSTV saves the decoded image into `sstv-images/inbox`.
10. Confirm the dashboard shows a clickable SSTV thumbnail for the node.

## Troubleshooting

- Dashboard unreachable: confirm `npm start` is running and `PORT` is set to `3000`.
- No JS8 messages: confirm JS8Call TCP API is enabled and `JS8CALL_HOST`/`JS8CALL_PORT` match.
- ACK not transmitted: confirm JS8Call is connected to the radio, PTT works from JS8Call, and the remote callsign mapping is correct.
- QSSTV does not decode: confirm QSSTV input is the receive audio path, not an output/speaker device.
- Audio sounds distorted: reduce `BEARWAVE_QSSTV_CAPTURE_VOLUME` and `BEARWAVE_JS8CALL_CAPTURE_VOLUME`.
- No SSTV thumbnails: confirm decoded image files are being saved into `sstv-images/inbox` and that `BEARWAVE_SSTV_IMAGE_DIR` matches that folder.
- Kiosk does not open: check `logs/desktop-start.log`, confirm the Pi desktop is running, and confirm Chromium is installed.

## Security And Repository Hygiene

This repository intentionally excludes:

- `node_modules/`
- `.env`
- `logs/`
- SSTV audio recordings and received images
- Python virtual environments

Generated dependencies should be recreated with `npm install` and Python virtual environments should be recreated from the instructions above.

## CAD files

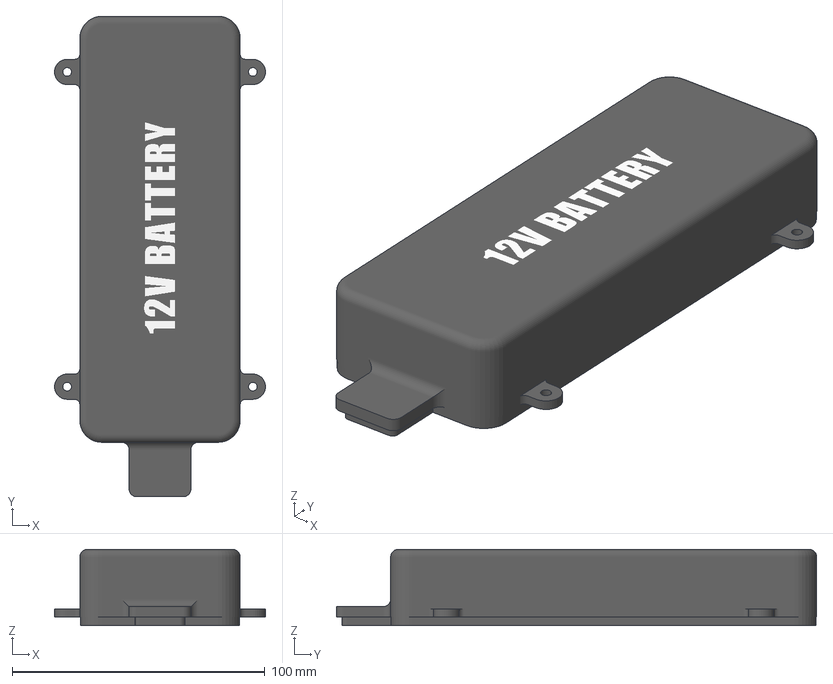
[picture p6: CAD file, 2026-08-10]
remote-node/hardware/enclosure/3mf/BatteryCover.3MF
83.4 x 189.9 x 30.2 mm

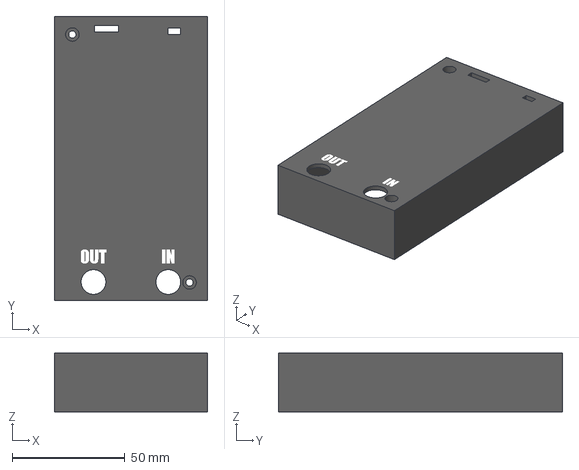
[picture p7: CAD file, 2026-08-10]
remote-node/hardware/enclosure/3mf/atu100Cover.3MF
68.0 x 126.0 x 26.0 mm

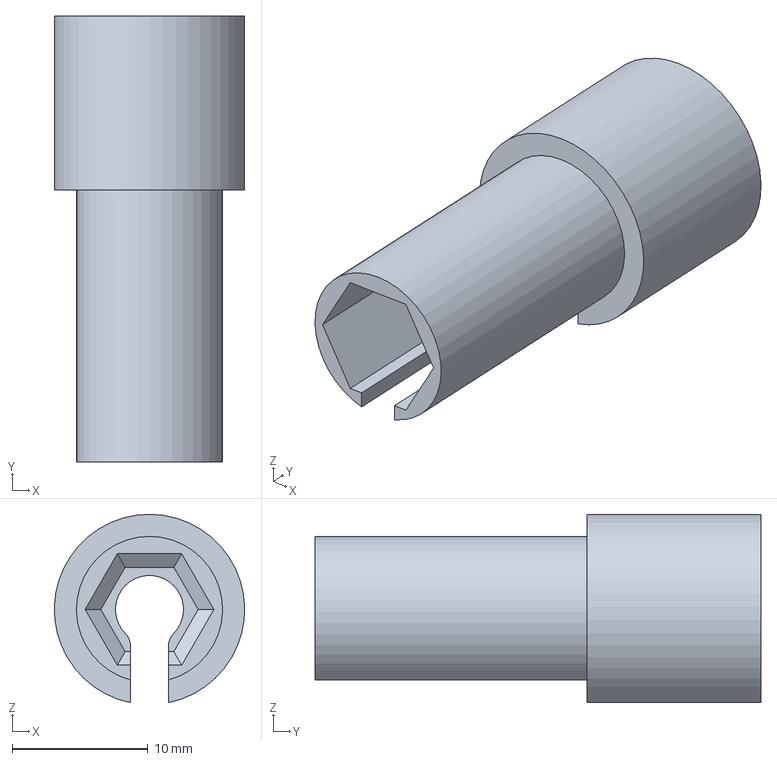
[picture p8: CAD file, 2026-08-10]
remote-node/hardware/enclosure/3mf/SMAnutspinner.3MF
14.0 x 32.8 x 13.9 mm

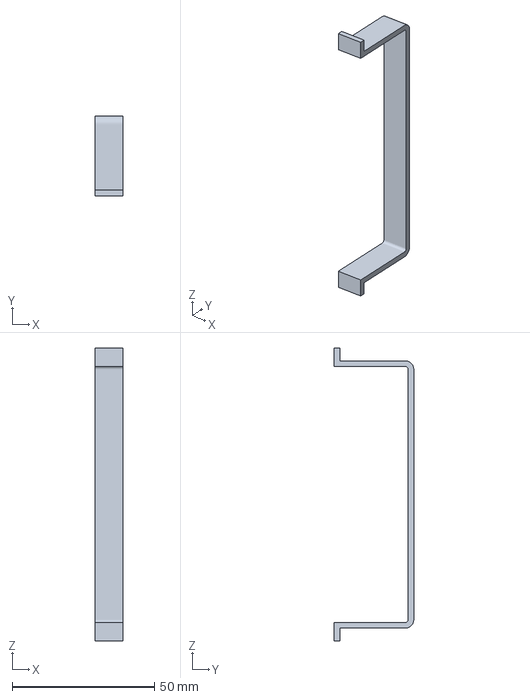
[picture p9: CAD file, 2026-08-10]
remote-node/hardware/enclosure/3mf/QDXClamp.3MF
10.0 x 28.0 x 103.0 mm

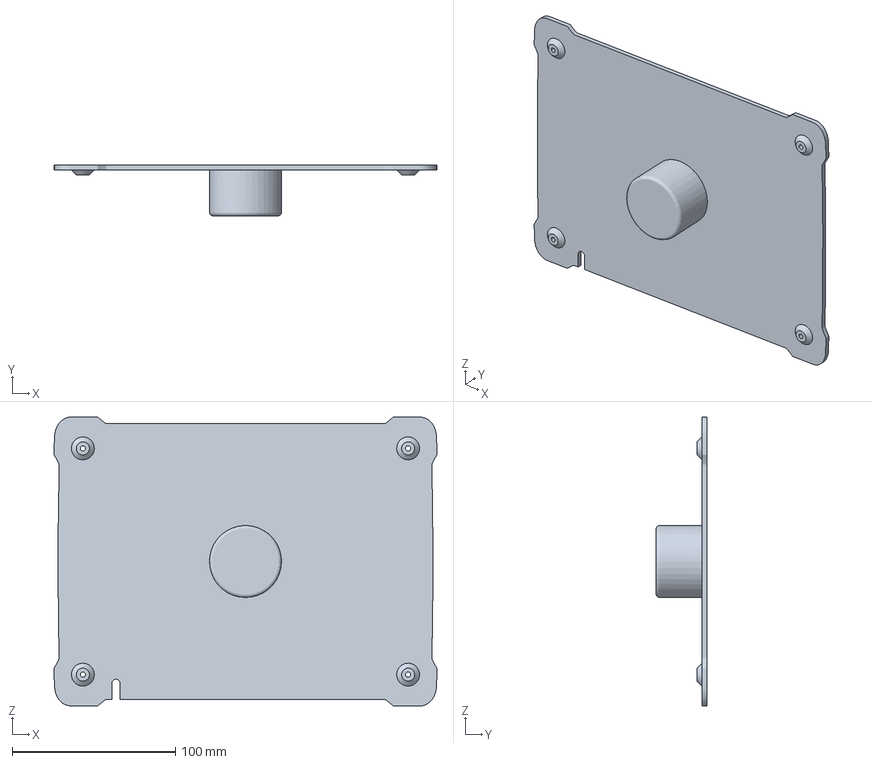
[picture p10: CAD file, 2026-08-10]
remote-node/hardware/enclosure/3mf/LidCover3MF.3MF
234.4 x 31.0 x 176.8 mm

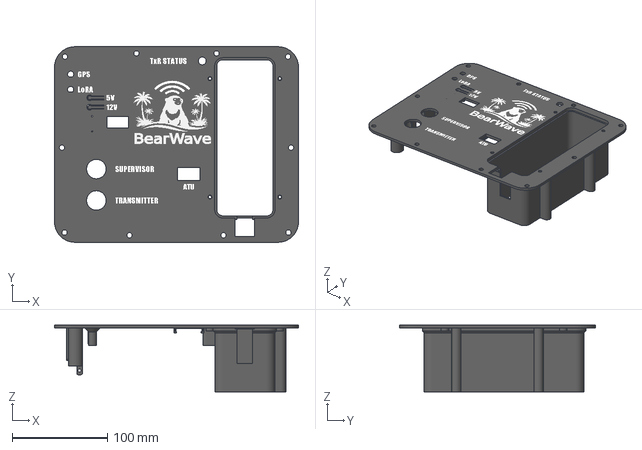
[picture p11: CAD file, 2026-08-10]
remote-node/hardware/enclosure/3mf/FrontPanel.3MF
256.4 x 205.6 x 70.0 mm

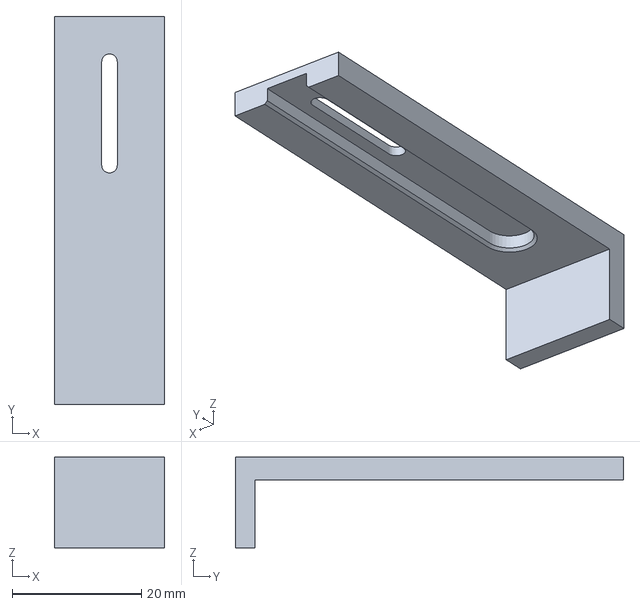
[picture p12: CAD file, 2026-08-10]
remote-node/hardware/enclosure/3mf/BatteryClip.3MF
17.0 x 60.0 x 14.0 mm

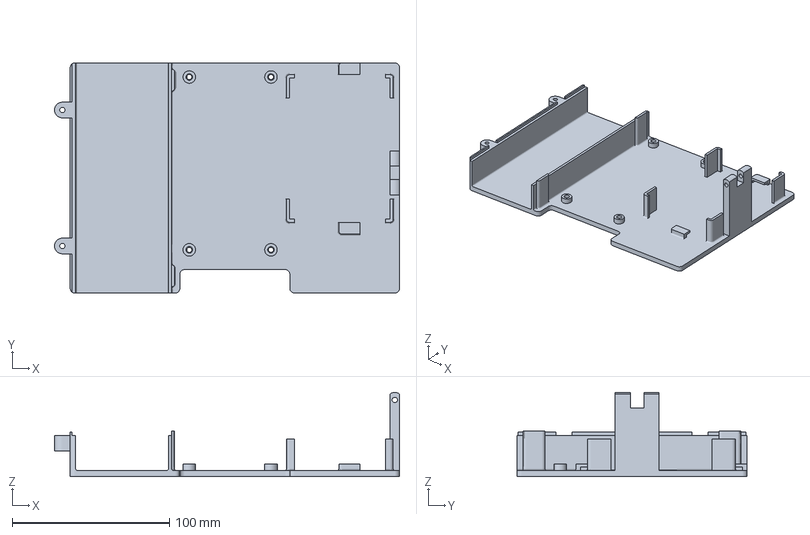
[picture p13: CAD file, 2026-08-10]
remote-node/hardware/enclosure/3mf/BasePlate.3MF
219.6 x 146.6 x 53.7 mm

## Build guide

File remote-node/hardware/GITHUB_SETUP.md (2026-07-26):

# GitHub Repository Setup - Hardware

## Repository Information

**Repository Name**: Hardware  
**Repository URL**: https://github.com/butterworthma/Hardware.git

## Current Status

✅ Repository initialized locally  
✅ All documentation files created  
✅ Initial commit completed  
✅ Remote configured

## Next Steps

### 1. Create GitHub Repository

If the repository doesn't exist on GitHub yet:

1. Go to: https://github.com/new
2. Repository name: `Hardware`
3. Description: "BearWave Hardware - Final Board Design Documentation"
4. Visibility: Choose Public or Private
5. **Do NOT** initialize with README, .gitignore, or license (we already have these)
6. Click "Create repository"

### 2. Push to GitHub

Once the repository is created on GitHub, run:

```bash
cd /Users/samanthabutterworth/PycharmProjects/pythonProject3/Hardware
git push -u origin main
```

If you need to authenticate, use your GitHub Personal Access Token.

### 3. Add Images

After pushing, add the board design images:

1. Place images in the `images/` directory:
   - `final_board_design_top.png` - Top view of complete board
   - `final_board_design_3d.png` - 3D rendering view
   - `pcb_layout_top.png` - Bare PCB layout (optional)
   - `schematic_diagram.png` - Circuit schematic (optional)

2. Commit and push:
```bash
git add images/*.png
git commit -m "Add board design images"
git push origin main
```

## Repository Structure

```
Hardware/
├── README.md                          # Main documentation
├── .gitignore                         # Git ignore rules
├── GITHUB_SETUP.md                    # This file
├── docs/
│   ├── BOM_Board1_Schematic1_2026-01-05.md  # Bill of Materials
│   ├── board_annotations.md           # Detailed component breakdown
│   ├── schematic.md                   # Circuit documentation
│   └── assembly.md                    # Assembly guide
└── images/
    ├── README.md                      # Image directory instructions
    └── [images to be added]           # Board design photos
```

## Documentation Created

1. **README.md** - Main repository documentation with overview
2. **BOM_Board1_Schematic1_2026-01-05.md** - Complete bill of materials
3. **board_annotations.md** - Detailed component-by-component breakdown
4. **schematic.md** - Complete circuit documentation
5. **assembly.md** - Step-by-step assembly instructions

## Notes

- All documentation is based on the provided images and BOM information
- Images should be added to the `images/` directory
- The BOM information is from the circuit schematic dated 2026-01-05
- Documentation follows the same style as the BearWave-Paper2 repository

## Related Repositories

- **Software/Analysis**: https://github.com/butterworthma/BearWave-Paper2
- **Hardware**: https://github.com/butterworthma/Hardware

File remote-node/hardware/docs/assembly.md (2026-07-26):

# BearWave Board Assembly Guide

## Overview

This guide provides step-by-step instructions for assembling the BearWave hardware platform. Follow these instructions carefully to ensure proper functionality and reliability.

---

## Prerequisites

### Tools Required:
- Soldering iron (temperature controlled, 350-400°C)
- Solder (lead-free recommended, 0.5-0.8mm diameter)
- Flux (rosin-based)
- Desoldering braid/wick
- Tweezers (ESD-safe)
- Multimeter
- Oscilloscope (optional, for testing)
- Hot air rework station (optional, for SMD components)

### Components:
- All components from BOM (see [BOM Documentation](BOM_Board1_Schematic1_2026-01-05.md))
- Raspberry Pi Zero 2 W
- Heltec V3.2 ESP32 Module
- GPS Module with battery
- Display Module
- XL6019E1 Boost Converter Modules (x2)
- Inductors (330µH, x4)
- Electrolytic capacitors (220µF 35V, x4)

---

## Assembly Order

### Step 1: Prepare the PCB

1. **Inspect PCB**:
   - Check for any manufacturing defects
   - Verify all pads and vias are properly plated
   - Check silkscreen alignment

2. **Clean PCB**:
   - Use isopropyl alcohol (99%+) to clean
   - Remove any flux residue or contamination
   - Allow to dry completely

---

### Step 2: Solder Passive Components (Bottom Side First)

**Resistors (R3-R14):**
1. Start with smallest components (0805 package)
2. Apply flux to pad
3. Place resistor with tweezers
4. Solder one pad, then the other
5. Verify resistance with multimeter

**Capacitors (C1-C4):**
1. Solder ceramic capacitors (0805 package)
2. Note: C1 is 1µF, C2-C4 are 100nF
3. Verify orientation (ceramic caps are non-polarized)

**Order**: Solder all 0805 components first, then move to larger components.

---

### Step 3: Solder Integrated Circuits

**RTC Module (U3 - DS3231M+):**
1. **Package**: SOIC-16
2. **Orientation**: Check pin 1 marking (usually dot or notch)
3. **Method**: 
   - Apply flux
   - Align IC carefully
   - Solder one corner pin first
   - Check alignment
   - Solder remaining pins
   - Use desoldering braid to remove bridges if needed
4. **Test**: Verify I2C communication after soldering

**Ideal Diode Controller (U4 - LTC4358CFE#PBF):**
1. **Package**: HTSSOP-16 (fine pitch)
2. **Orientation**: Critical - verify pin 1 location
3. **Method**: 
   - Use fine tip soldering iron or hot air
   - Apply flux generously
   - Carefully align IC
   - Solder with care (fine pitch requires precision)
4. **Test**: Verify continuity after soldering

---

### Step 4: Solder Power Components

**Fuses (F1, F2):**
1. **Type**: 3557-2 fuse holders
2. **Installation**: 
   - Insert fuse holders
   - Solder from top side
   - Ensure secure mechanical connection
3. **Note**: Do not insert fuses until final testing

**Inductors:**
1. **Value**: 330µH (x4)
2. **Installation**: 
   - Solder to boost converter areas
   - Ensure good thermal connection
   - Verify no shorts to adjacent pads

**Electrolytic Capacitors:**
1. **Value**: 220µF 35V (x4)
2. **Orientation**: **CRITICAL** - negative terminal marked
3. **Installation**:
   - Verify polarity before soldering
   - Solder positive terminal first
   - Ensure proper clearance from other components

---

### Step 5: Install Connectors and Headers

**Screw Terminals (ST1-ST5):**
1. **Type**: KF301-5.0-2P (5mm pitch)
2. **Installation**:
   - Insert from top side
   - Solder from bottom
   - Ensure terminals are straight and secure
3. **Labels**: Verify correct placement per schematic

**GPIO Headers:**
1. **Installation**: 
   - Insert male pin headers
   - Solder from bottom
   - Ensure pins are straight and perpendicular
2. **Verification**: Check pin spacing matches Raspberry Pi header

**Test Points (Pogo1, Pogo2):**
1. **Type**: SMD test points
2. **Installation**: Solder with hot air or fine tip iron
3. **Function**: For debugging and testing

---

### Step 6: Install LEDs and Diodes

**LEDs (LED1, LED2):**
1. **Type**: HL-PC-2012U97GC-L (0805 package)
2. **Orientation**: **CRITICAL** - anode/cathode must be correct
3. **Installation**:
   - Verify polarity (usually marked on package)
   - Solder with correct orientation
   - Test with multimeter (diode mode)

**Diode (D1):**
1. **Type**: MMBD1205 (SOT-23-3)
2. **Orientation**: Check marking on package
3. **Installation**: Solder with correct orientation

---

### Step 7: Install Crystal and Battery Holder

**Crystal (CR1):**
1. **Type**: 32.768kHz (MY-1225-01-J)
2. **Installation**: 
   - Solder carefully (crystals are fragile)
   - Ensure good connection
   - Avoid excessive heat

**RTC Battery Holder:**
1. **Type**: CR1225 coin cell holder
2. **Installation**: 
   - Solder from bottom
   - Ensure secure mechanical connection
3. **Note**: Do not insert battery until RTC is tested

---

### Step 8: Install Modules

**Raspberry Pi Zero 2 W:**
1. **Mounting**: Use standoffs (supplied separately)
2. **Installation**:
   - Align GPIO header with board connector
   - Secure with standoffs
   - Ensure proper alignment
   - Connect GPIO header (40-pin)
3. **Verification**: Check all pins make contact

**Heltec V3.2 ESP32 Module:**
1. **Connection**: Via headers or direct connection
2. **Installation**: 
   - Align pins carefully
   - Secure connection
   - Verify UART and I2C connections

**GPS Module:**
1. **Installation**: 
   - Connect to designated headers
   - Verify UART connections (GPS_TX, GPS_RX)
   - Install backup battery if required

**Boost Converter Modules (U6, U7):**
1. **Installation**: 
   - Mount XL6019E1 modules
   - Connect to inductor pads
   - Verify input/output connections
2. **Testing**: Test output voltages before full assembly

**Display Module:**
1. **Installation**: 
   - Connect USB-C interface
   - Secure mounting
   - Verify connections

---

### Step 9: Final Assembly

1. **Insert Fuses**:
   - F2: Input fuse (5A)
   - F1: Output fuse (12V circuit)
   - Verify fuse ratings

2. **Insert Batteries**:
   - RTC: CR1225 coin cell
   - GPS: Backup battery (if required)

3. **Final Inspection**:
   - Check all solder joints
   - Verify component orientation
   - Check for shorts (use multimeter)
   - Verify no loose components

---

## Testing Procedure

### Pre-Power Tests:

1. **Continuity Check**:
   - Verify no shorts between power rails
   - Check ground connections
   - Verify signal paths

2. **Resistance Check**:
   - Measure power rail resistance (should not be near zero)
   - Verify pull-up resistors (4.7KΩ, etc.)

### Power-On Tests:

1. **Power Rails** (with multimeter):
   - 3.3V rail: Should read 3.3V ±5%
   - 5V rail: Should read 5.0V ±5%
   - 12V rail: Should read 12.0V ±5%

2. **Current Draw**:
   - Measure input current (should be reasonable)
   - Check for excessive current (indicates problem)

3. **LED Indicators**:
   - LED1: Should indicate 5V power
   - LED2: Should indicate 12V power

4. **Communication Tests**:
   - I2C: Verify RTC communication
   - UART: Test GPS communication
   - SPI: Test if applicable

5. **Module Tests**:
   - Raspberry Pi: Boot and verify operation
   - ESP32: Verify WiFi/Bluetooth
   - GPS: Verify lock and data
   - RTC: Verify timekeeping

---

## Troubleshooting

### Common Issues:

1. **No Power**:
   - Check fuse (F2)
   - Verify battery connection
   - Check reverse polarity protection

2. **Incorrect Voltages**:
   - Verify boost converter connections
   - Check inductor connections
   - Verify feedback resistors

3. **Communication Failures**:
   - Check I2C pull-up resistors
   - Verify UART connections
   - Check power to modules

4. **RTC Not Working**:
   - Verify battery installed
   - Check I2C connections
   - Verify crystal connection

5. **LEDs Not Working**:
   - Check LED orientation
   - Verify current limiting resistors
   - Check enable jumpers

---

## Safety Considerations

1. **ESD Protection**: Use ESD-safe workspace
2. **Temperature**: Avoid excessive soldering iron heat
3. **Ventilation**: Ensure good ventilation when soldering
4. **Power**: Never apply power during assembly
5. **Testing**: Test with current-limited power supply first

---

## Post-Assembly

1. **Conformal Coating** (optional):
   - Apply for field deployment
   - Protects against humidity
   - Follow manufacturer instructions

2. **Documentation**:
   - Record serial numbers
   - Note any modifications
   - Document test results

3. **Calibration** (if required):
   - RTC time accuracy
   - GPS performance
   - Power consumption

---

## Revision History

- **2026-01-05**: Initial assembly guide (V1.0)

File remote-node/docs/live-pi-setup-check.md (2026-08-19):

# Live Remote Pi Setup Check

Checked against remote node `192.168.1.182` on 2026-07-26.

## Live Paths

```text
/home/mark/bearwave
/home/mark/bearwave/app
/home/mark/bearwave/scripts
/home/mark/bearwave/logs
/home/mark/bearwave/state
/home/mark/bearwave/sstv
```

## Systemd

The live service is installed system-wide, not as a user service:

```text
/etc/systemd/system/bearwave-cycle.service
```

It is enabled:

```text
bearwave-cycle.service enabled
```

The service runs:

```text
ExecStart=/home/mark/bearwave/scripts/bearwave_boot_cycle.sh
User=root
WantedBy=graphical.target
```

The service showed `failed` during the check only because it had been manually stopped for editing/testing:

```text
code=killed, signal=TERM
```

That matches the bench-test history and is not treated as a setup mismatch.

## Dependency Check

Live command/module status:

```text
rpicam-still OK
aplay OK
ffmpeg OK
js8call OK
rigctl expected through libhamlib-utils on Debian Trixie
convert missing
serial OK 3.5
PIL OK 12.2.0
pysstv OK
```

`convert` is no longer required because the current SSTV path uses Pillow through `remote-pi/app/sstv_image.py`.

## Audio/Radio Check

`aplay -l` showed the QDX:

```text
card 3: Transceiver [QDX Transceiver], device 0: USB Audio [USB Audio]
```

The SSTV transmit helper therefore defaults to:

```text
plughw:CARD=Transceiver,DEV=0
```

## Live SSTV Configuration

The live `bearwave_boot_cycle.sh` uses:

```bash
SSTV_ENABLED="${BEARWAVE_SSTV_ENABLED:-1}"
SSTV_DRY_RUN="${BEARWAVE_SSTV_DRY_RUN:-0}"
SSTV_REPEAT_COUNT="${BEARWAVE_SSTV_REPEAT_COUNT:-1}"
SSTV_MODE="${BEARWAVE_SSTV_MODE:-ScottieS1}"
SSTV_WORK_DIR="${BEARWAVE_SSTV_WORK_DIR:-/home/mark/bearwave/sstv}"
SSTV_PILLOW_PYTHON="${BEARWAVE_SSTV_PILLOW_PYTHON:-/usr/bin/python3}"
```

Capture:

```bash
rpicam-still -o {image} --width 1280 --height 960 --timeout 1000 --nopreview
```

Encode:

```bash
/home/mark/bearwave/.venv/bin/python -m pysstv --mode {mode} {prepared} {wav}
```

Transmit:

```bash
/home/mark/bearwave/scripts/sstv_transmit_qdx.sh {wav}
```

## Differences From Old Setup Instructions

The old setup material described a generic headless JS8Call/noVNC Pi. The live BearWave remote node differs:

- It uses `/home/mark/bearwave`, not a generic `pi` user layout.
- It uses ESP32-supervised power and `/dev/serial0`.
- It uses a system-wide `bearwave-cycle.service`.
- It launches JS8Call through the desktop `.desktop` launcher when a real display is present, or directly under Xvfb on display `:99` when the node is headless.
- It includes SSTV capture/encode/transmit after acknowledged alarms.
- It uses Pillow/PySSTV rather than ImageMagick `convert`.
- It uses QDX PTT through `rigctl` and WAV playback through `aplay`.

The GitHub README and file layout have been updated to match the live Pi rather than the old noVNC package.

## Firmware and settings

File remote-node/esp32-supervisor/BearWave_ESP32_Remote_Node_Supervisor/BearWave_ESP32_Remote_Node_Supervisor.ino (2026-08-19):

/*
  BearWave Heltec RTC / GPS / OLED / Pi-UART bridge
  -------------------------------------------------

  REMOTE-NODE SUPERVISOR VERSION FOR BEARWAVE PCB V2
  --------------------------------------------------

  Purpose:
    This ESP32/Heltec sketch supervises the BearWave remote node hardware.
    It powers the Raspberry Pi and radio, provides GPS/RTC/time/event state
    to the Pi over UART, accepts shutdown signalling from the Pi, cuts the
    switched power rails, and then enters deep sleep until the next wake cycle.

  Key hardware behaviour:
    BearWave PCB V2 uses flip-flop latch circuits for the high-power rails:
      - 5 V rail for the Raspberry Pi Zero 2 W
      - 12 V rail for the QDX/radio/ATU path

    The ESP32 does not hold a rail-enable level during deep sleep. Instead, it
    briefly drives the relevant ENABLE*PULSE line HIGH to emulate the latch
    push-button pulse proven on the PCB V2 bench unit, then returns the output
    LOW while idle. The external latch preserves the rail state while the ESP32
    sleeps.

    Rail status is read back using 5VOK and 12VOK so the firmware only pulses a
    latch when the measured rail state does not match the requested state.

  Diagnostic method:
    USB serial must not be connected during the full power test because USB 5 V
    can back-feed the Raspberry Pi. Therefore, the OLED is used as the primary
    diagnostic console.

  OLED diagnostics show:
    - boot count
    - reset reason
    - wake reason
    - 5 V and 12 V rail state
    - last shutdown stage

  Expected healthy wake after sleep:
    Reset: DEEPSLEEP
    Wake:  TIMER

  UART command summary for the Pi:

    PING
      -> PONG

    STATUS?
      -> OK,BEARWAVE_RTC_GPS_EVENTS

    TIME?
      -> TIME,YYYY-MM-DDTHH:MM:SSZ
      -> ERR,RTC_READ
      -> ERR,RTC_INVALID

    BAT?
      -> BAT,<voltage>,<percent>

    COORD?
      -> COORD,<lat>,<lon>
      -> COORD,INVALID

    EVENT?
      -> EVENT,NONE
      -> EVENT,TRAP
      -> EVENT,LOW_BAT
      -> EVENT,TRAP+LOW_BAT

    EVENT_RAW?
      -> RAW,<trap1>,<trap2>,<trapLatched>,<trapReported>,<lowBatActive>,<lowBatReported>

    EVENT_ACKED,TRAP
      -> OK,EVENT_ACKED,TRAP

    EVENT_ACKED,LOW_BAT
      -> OK,EVENT_ACKED,LOW_BAT

    EVENT_ACKED,ALL
      -> OK,EVENT_ACKED,ALL

    SHUTDOWN
      -> OK,SHUTDOWN_RECEIVED
      The ESP32 then waits PI_POWER_CUT_DELAY_MS, turns off the 12 V rail,
      turns off the 5 V rail, isolates the Pi UART pins, and enters deep sleep.

  Test/deployment note:
    WAKE_INTERVAL_US is currently set to 5 minutes for test. Change it back
    to 15 minutes once the behaviour is proven.
*/

#include <Wire.h>
#include <TinyGPSPlus.h>
#include "SSD1306Wire.h"
#include "pins_arduino.h"
#include "esp_sleep.h"
#include "driver/gpio.h"
#include "driver/rtc_io.h"

// ============================================================
// RTC DS3231 configuration
// ============================================================

#define RTC_SDA_PIN    40
#define RTC_SCL_PIN    39
#define RTC_INT_PIN    6
#define DS3231_ADDR    0x68

// ============================================================
// GPS configuration
// ============================================================

#define VEXT_CTRL_PIN  36
#define GPS_RX_PIN     41
#define GPS_TX_PIN     42
#define GPS_BAUD       9600

// ============================================================
// Battery measurement configuration
// ============================================================

#define BATTERY_ADC_PIN 2

#define ADC_MAX_COUNTS        4095.0f
#define ADC_REF_VOLTAGE       3.3f
#define BATTERY_DIVIDER_RATIO 5.0f

#define BATTERY_FLAT_VOLTAGE  11.0f
#define BATTERY_FULL_VOLTAGE  12.6f

#define LOW_BATTERY_ASSERT_VOLTAGE 11.30f
#define LOW_BATTERY_CLEAR_VOLTAGE  11.60f

// ============================================================
// Raspberry Pi UART configuration
// ============================================================

#define PI_UART_RX_PIN 33
#define PI_UART_TX_PIN 34
#define PI_UART_BAUD   115200

// ============================================================
// BearWave PCB V2 latch-based power control
// ============================================================

#define PSU_5V_PULSE_PIN   7
#define PSU_12V_PULSE_PIN  38
#define PSU_5V_OK_PIN      47
#define PSU_12V_OK_PIN     48
#define PSU_5V_OK_ACTIVE_LEVEL   LOW
#define PSU_12V_OK_ACTIVE_LEVEL  LOW

/*
  V2 power latch convention:
    ENABLE5VPULSE / ENABLE12VPULSE are momentary latch inputs that were
    bench-proven to toggle from a driven HIGH pulse.
    5VOK / 12VOK are rail-present status inputs. The current PCB V2 bench unit
    presents both 5VOK and 12VOK as active-low open-drain/open-collector style
    signals. The ESP32 enables internal pull-ups so OFF reads HIGH and ON reads
    LOW.

  Confirmed PCB V2 ESP32 GPIO assignments:
    PI UART RX    -> GPIO33  (ESP32 receives from Raspberry Pi TX)
    PI UART TX    -> GPIO34  (ESP32 transmits to Raspberry Pi RX)
    GPS UART RX   -> GPIO41  (ESP32 receives from GPS TX)
    GPS UART TX   -> GPIO42  (ESP32 transmits to GPS RX)
    RTC SDA       -> GPIO40
    RTC SCL       -> GPIO39
    RTC INT       -> GPIO6
    5VOK          -> GPIO47
    12VOK         -> GPIO48
    ENABLE5VPULSE -> GPIO7
    ENABLE12VPULSE-> GPIO38
    Battery ADC   -> GPIO2
    Trap switch 1 -> GPIO5
    Trap switch 2 -> GPIO4
*/
const unsigned long PSU_LATCH_PULSE_MS = 250UL;
const unsigned long PSU_LATCH_SETTLE_MS = 1000UL;
const unsigned long PI_POWER_CUT_DELAY_MS = 50000UL;
const unsigned long PI_MAX_ON_TIME_MS = 20UL * 60UL * 1000UL;

/*
  TEST SLEEP INTERVAL
  -------------------
  Current value is 5 minutes for diagnostics.

  For the 15-minute test cycle, use:
    const uint64_t WAKE_INTERVAL_US = 15ULL * 60ULL * 1000000ULL;
*/
const uint64_t WAKE_INTERVAL_US = 5ULL * 60ULL * 1000000ULL;

// ============================================================
// Trap/alarm input configuration
// ============================================================

#define TRAP_PIN_1 5
#define TRAP_PIN_2 4

const uint64_t TRAP_WAKE_MASK =
  (1ULL << TRAP_PIN_1) |
  (1ULL << TRAP_PIN_2);

// ============================================================
// General timing configuration
// ============================================================

const unsigned long DISPLAY_UPDATE_MS       = 1000UL;
const unsigned long RTC_CHECK_INTERVAL_MS   = 15000UL;
const unsigned long GPS_POWERUP_DELAY_MS    = 3000UL;
const unsigned long GPS_SYNC_TIMEOUT_MS     = 180000UL;
const unsigned long GPS_FRESH_AGE_MS        = 2000UL;
const long MAX_ALLOWED_DRIFT_SECONDS        = 1;
const unsigned long EVENT_POLL_INTERVAL_MS  = 200UL;

// ============================================================
// OLED display object
// ============================================================

SSD1306Wire display(0x3c, SDA_OLED, SCL_OLED);

// ============================================================
// Separate I2C bus for the RTC
// ============================================================

TwoWire RTCWire = TwoWire(1);

// ============================================================
// Global objects
// ============================================================

TinyGPSPlus gps;
HardwareSerial GPSSerial(1);
HardwareSerial PiSerial(2);

// ============================================================
// Runtime timing state
// ============================================================

unsigned long lastDisplayUpdate = 0;
unsigned long lastRtcCheck = 0;
unsigned long lastEventPoll = 0;
unsigned long highPowerRailsOnAt = 0;
bool highPowerRailsRequestedOn = false;

// ============================================================
// Pi UART receive buffer
// ============================================================

String piRxLine;

// ============================================================
// Event / alarm state model
// ============================================================

bool trapLatched = false;
bool trapReported = false;

bool lowBatteryActive = false;
bool lowBatteryReported = false;

bool shutdownRequested = false;
unsigned long shutdownRequestTime = 0;

// ============================================================
// Deep-sleep retained diagnostic state
// ============================================================

RTC_DATA_ATTR int bootCount = 0;
RTC_DATA_ATTR int lastShutdownStage = 0;

// ============================================================
// Forward declarations
// ============================================================

void servicePiUart();
void updateEventState();
void updateDisplay();
void serviceShutdownSequence();
void serviceHighPowerFailsafe();

// ============================================================
// Text helpers for reset/wake diagnostics
// ============================================================

String resetReasonText() {
  esp_reset_reason_t reason = esp_reset_reason();

  switch (reason) {
    case ESP_RST_POWERON:
      return "POWERON";
    case ESP_RST_EXT:
      return "EXT";
    case ESP_RST_SW:
      return "SW";
    case ESP_RST_PANIC:
      return "PANIC";
    case ESP_RST_INT_WDT:
      return "INT_WDT";
    case ESP_RST_TASK_WDT:
      return "TASK_WDT";
    case ESP_RST_WDT:
      return "WDT";
    case ESP_RST_DEEPSLEEP:
      return "DEEPSLEEP";
    case ESP_RST_BROWNOUT:
      return "BROWNOUT";
    default:
      return "UNKNOWN";
  }
}

String wakeReasonText() {
  esp_sleep_wakeup_cause_t cause = esp_sleep_get_wakeup_cause();

  switch (cause) {
    case ESP_SLEEP_WAKEUP_UNDEFINED:
      return "UNDEFINED";
    case ESP_SLEEP_WAKEUP_TIMER:
      return "TIMER";
    case ESP_SLEEP_WAKEUP_EXT0:
      return "EXT0";
    case ESP_SLEEP_WAKEUP_EXT1:
      return "EXT1";
    case ESP_SLEEP_WAKEUP_GPIO:
      return "GPIO";
    case ESP_SLEEP_WAKEUP_UART:
      return "UART";
    default:
      return "OTHER";
  }
}

String railStateText() {
  String five = digitalRead(PSU_5V_OK_PIN) == PSU_5V_OK_ACTIVE_LEVEL ? "5ON" : "5OFF";
  String twelve = digitalRead(PSU_12V_OK_PIN) == PSU_12V_OK_ACTIVE_LEVEL ? "12ON" : "12OFF";
  return five + "/" + twelve;
}

// ============================================================
// OLED diagnostic display helpers
// ============================================================

void showDiagScreen(const String &stage) {
  display.clear();
  display.setTextAlignment(TEXT_ALIGN_LEFT);
  display.setFont(ArialMT_Plain_10);

  display.drawString(0, 0,  "BearWave diag");
  display.drawString(0, 10, "Boot:" + String(bootCount));
  display.drawString(0, 20, "R:" + resetReasonText());
  display.drawString(0, 30, "W:" + wakeReasonText());
  display.drawString(0, 40, "Rail:" + railStateText());
  display.drawString(0, 50, stage);

  display.display();
}

void showStage(const String &stage, unsigned long holdMs = 1000) {
  showDiagScreen(stage);
  delay(holdMs);
}

void showLastBootDetails(unsigned long holdMs = 5000) {
  display.clear();
  display.setTextAlignment(TEXT_ALIGN_LEFT);
  display.setFont(ArialMT_Plain_10);

  display.drawString(0, 0,  "Last stage:" + String(lastShutdownStage));
  display.drawString(0, 12, "Boot:" + String(bootCount));
  display.drawString(0, 24, "Reset:" + resetReasonText());
  display.drawString(0, 36, "Wake:" + wakeReasonText());
  display.drawString(0, 48, "Rail:" + railStateText());

  display.display();

  delay(holdMs);
}

// ============================================================
// Heltec OLED power and reset helpers
// ============================================================

void VextON(void) {
  pinMode(Vext, OUTPUT);
  digitalWrite(Vext, LOW);
}

void VextOFF(void) {
  pinMode(Vext, OUTPUT);
  digitalWrite(Vext, HIGH);
}

void displayReset(void) {
  pinMode(RST_OLED, OUTPUT);

  digitalWrite(RST_OLED, HIGH);
  delay(1);

  digitalWrite(RST_OLED, LOW);
  delay(1);

  digitalWrite(RST_OLED, HIGH);
  delay(1);
}

// ============================================================
// BearWave PCB V2 latch-based power helpers
// ============================================================

bool rail5VOn() {
  return digitalRead(PSU_5V_OK_PIN) == PSU_5V_OK_ACTIVE_LEVEL;
}

bool rail12VOn() {
  return digitalRead(PSU_12V_OK_PIN) == PSU_12V_OK_ACTIVE_LEVEL;
}

void configurePowerLatchPinsIdle() {
  /*
    The BearWave PCB V2 latch inputs have been bench-proven to respond to a
    driven HIGH pulse from the Heltec GPIO. Keep the pulse outputs LOW when
    idle, then briefly drive HIGH to emulate the latch push.
  */
  pinMode(PSU_5V_PULSE_PIN, OUTPUT);
  pinMode(PSU_12V_PULSE_PIN, OUTPUT);
  digitalWrite(PSU_5V_PULSE_PIN, LOW);
  digitalWrite(PSU_12V_PULSE_PIN, LOW);

  pinMode(PSU_5V_OK_PIN, INPUT_PULLUP);
  pinMode(PSU_12V_OK_PIN, INPUT_PULLUP);
}

void pulseLatchHigh(uint8_t pin, const char *label) {
  Serial.print("Pulsing ");
  Serial.print(label);
  Serial.println(" latch");

  pinMode(pin, OUTPUT);
  digitalWrite(pin, LOW);
  delay(20);
  digitalWrite(pin, HIGH);
  delay(PSU_LATCH_PULSE_MS);
  digitalWrite(pin, LOW);
  delay(20);
}

bool ensureRailState(const char *label, uint8_t pulsePin, uint8_t okPin, bool shouldBeOn) {
  bool activeLevel = okPin == PSU_12V_OK_PIN ? PSU_12V_OK_ACTIVE_LEVEL : PSU_5V_OK_ACTIVE_LEVEL;
  bool isOn = digitalRead(okPin) == activeLevel;

  Serial.print(label);
  Serial.print(" rail currently ");
  Serial.println(isOn ? "ON" : "OFF");

  showStage(String(label) + (isOn ? " is ON" : " is OFF"), 800);

  if (isOn == shouldBeOn) {
    Serial.print(label);
    Serial.println(" rail already in requested state");
    showStage(String(label) + " already OK", 800);
    return true;
  }

  showStage(String("Pulse ") + label, 800);
  pulseLatchHigh(pulsePin, label);
  delay(PSU_LATCH_SETTLE_MS);

  bool nowOn = digitalRead(okPin) == activeLevel;

  Serial.print(label);
  Serial.print(" rail after pulse ");
  Serial.println(nowOn ? "ON" : "OFF");

  showStage(String(label) + (nowOn == shouldBeOn ? " OK" : " FAIL"), 1500);

  return nowOn == shouldBeOn;
}

void powerPiAndRadioOn() {
  /*
    Bring the Pi rail up first, then the radio rail. The Pi boot script waits
    for JS8Call/radio readiness, so a short delay between rails is sufficient
    for deterministic bench testing.
  */
  bool fiveOk = ensureRailState("5V", PSU_5V_PULSE_PIN, PSU_5V_OK_PIN, true);

  if (!fiveOk) {
    Serial.println("ERROR: 5V rail did not confirm ON; leaving 12V rail off");
    showStage("5V ON FAIL", 2500);
    return;
  }

  delay(1000);
  bool twelveOk = ensureRailState("12V", PSU_12V_PULSE_PIN, PSU_12V_OK_PIN, true);

  if (fiveOk || twelveOk) {
    highPowerRailsRequestedOn = true;
    highPowerRailsOnAt = millis();
  }

  if (!fiveOk || !twelveOk) {
    Serial.println("WARNING: requested rail ON state was not confirmed");
  }
}

bool powerPiAndRadioOff() {
  /*
    Remove radio/ATU power first, then remove the Pi rail after Linux has had
    PI_POWER_CUT_DELAY_MS to halt.
  */
  bool twelveOk = ensureRailState("12V", PSU_12V_PULSE_PIN, PSU_12V_OK_PIN, false);
  delay(1000);
  bool fiveOk = ensureRailState("5V", PSU_5V_PULSE_PIN, PSU_5V_OK_PIN, false);

  bool offOk = fiveOk && twelveOk;

  if (!offOk) {
    Serial.println("WARNING: requested rail OFF state was not confirmed");
  } else {
    highPowerRailsRequestedOn = false;
    highPowerRailsOnAt = 0;
  }

  return offOk;
}

bool normaliseRailsOffAtBoot() {
  /*
    Flip-flop latches preserve their state across ESP32 resets and sleep. During
    bench testing that can leave the 5 V or 12 V rail on before the supervisor
    starts a fresh cycle. Force both high-power rails off first so the later
    boot sequence always starts from a known state.
  */
  showStage("Check rails", 1000);

  bool twelveOffOk = ensureRailState("12V", PSU_12V_PULSE_PIN, PSU_12V_OK_PIN, false);
  delay(1000);
  bool fiveOffOk = ensureRailState("5V", PSU_5V_PULSE_PIN, PSU_5V_OK_PIN, false);

  if (twelveOffOk && fiveOffOk) {
    showStage("Rails are OFF", 1500);
    return true;
  }

  showStage("Rail off FAIL", 2500);
  Serial.println("WARNING: one or more rails failed to confirm OFF at boot");
  return false;
}

void bootRailControlTest() {
  /*
    Bench-test the latch control path on every ESP32 boot:
      1. read rail state
      2. force 12 V and 5 V off
      3. hold off for 5 seconds so the operator can confirm the rails dropped

    The rails remain OFF after this test. They are turned back ON later only
    when the supervisor is ready to wake the Pi/radio for a heartbeat or alarm
    cycle.
  */
  showStage("Rail boot test", 1500);

  normaliseRailsOffAtBoot();

  showStage("Rails OFF hold", 5000);
}

// ============================================================
// Pi UART isolation helper
// ============================================================

void isolatePiUartBeforeSleep() {
  /*
    Prevent the ESP32 UART pins from back-powering the Raspberry Pi through
    GPIO protection paths after the 5 V Pi rail is switched off.
  */
  PiSerial.end();

  pinMode(PI_UART_TX_PIN, INPUT);
  pinMode(PI_UART_RX_PIN, INPUT);
}

// ============================================================
// BCD conversion helpers
// ============================================================

uint8_t bcdToDec(uint8_t val) {
  return ((val >> 4) * 10) + (val & 0x0F);
}

uint8_t decToBcd(uint8_t val) {
  return ((val / 10) << 4) | (val % 10);
}

// ============================================================
// RTC helpers
// ============================================================

bool readDS3231Raw(uint8_t &sec, uint8_t &minu, uint8_t &hour,
                   uint8_t &dayOfWeek, uint8_t &dayOfMonth,
                   uint8_t &month, uint16_t &year) {
  RTCWire.beginTransmission(DS3231_ADDR);
  RTCWire.write(0x00);

  if (RTCWire.endTransmission(false) != 0) {
    return false;
  }

  uint8_t bytesReceived = RTCWire.requestFrom(DS3231_ADDR, (uint8_t)7);

  if (bytesReceived != 7) {
    return false;
  }

  uint8_t rawSec   = RTCWire.read();
  uint8_t rawMin   = RTCWire.read();
  uint8_t rawHour  = RTCWire.read();
  uint8_t rawDOW   = RTCWire.read();
  uint8_t rawDOM   = RTCWire.read();
  uint8_t rawMonth = RTCWire.read();
  uint8_t rawYear  = RTCWire.read();

  sec  = bcdToDec(rawSec & 0x7F);
  minu = bcdToDec(rawMin & 0x7F);

  if (rawHour & 0x40) {
    uint8_t hr = bcdToDec(rawHour & 0x1F);
    bool pm = rawHour & 0x20;

    if (pm && hr < 12) {
      hr += 12;
    }

    if (!pm && hr == 12) {
      hr = 0;
    }

    hour = hr;
  } else {
    hour = bcdToDec(rawHour & 0x3F);
  }

  dayOfWeek  = bcdToDec(rawDOW & 0x07);
  dayOfMonth = bcdToDec(rawDOM & 0x3F);
  month      = bcdToDec(rawMonth & 0x1F);
  year       = 2000 + bcdToDec(rawYear);

  return true;
}

bool writeDS3231(uint8_t sec, uint8_t minu, uint8_t hour,
                 uint8_t dayOfWeek, uint8_t dayOfMonth,
                 uint8_t month, uint16_t year) {
  RTCWire.beginTransmission(DS3231_ADDR);

  RTCWire.write(0x00);
  RTCWire.write(decToBcd(sec));
  RTCWire.write(decToBcd(minu));
  RTCWire.write(decToBcd(hour));
  RTCWire.write(decToBcd(dayOfWeek));
  RTCWire.write(decToBcd(dayOfMonth));
  RTCWire.write(decToBcd(month));
  RTCWire.write(decToBcd((uint8_t)(year - 2000)));

  return (RTCWire.endTransmission() == 0);
}

bool rtcLooksSane(uint16_t year, uint8_t month, uint8_t day,
                  uint8_t hour, uint8_t minute, uint8_t second) {
  if (year < 2024 || year > 2099) return false;
  if (month < 1 || month > 12) return false;
  if (day < 1 || day > 31) return false;
  if (hour > 23) return false;
  if (minute > 59) return false;
  if (second > 59) return false;

  return true;
}

// ============================================================
// Time conversion helpers
// ============================================================

long long daysFromCivil(int y, unsigned m, unsigned d) {
  y -= m <= 2;

  const int era = (y >= 0 ? y : y - 399) / 400;
  const unsigned yoe = (unsigned)(y - era * 400);
  const unsigned doy = (153 * (m + (m > 2 ? -3 : 9)) + 2) / 5 + d - 1;
  const unsigned doe = yoe * 365 + yoe / 4 - yoe / 100 + doy;

  return era * 146097LL + (long long)doe - 719468LL;
}

time_t utcToEpoch(uint16_t year, uint8_t month, uint8_t day,
                  uint8_t hour, uint8_t minute, uint8_t second) {
  long long days = daysFromCivil(year, month, day);
  long long secs = days * 86400LL + hour * 3600LL + minute * 60LL + second;

  return (time_t)secs;
}

uint8_t calculateDayOfWeek(uint16_t year, uint8_t month, uint8_t day) {
  static const uint8_t t[] = {0, 3, 2, 5, 0, 3, 5, 1, 4, 6, 2, 4};

  uint16_t y = year;

  if (month < 3) {
    y -= 1;
  }

  uint8_t dow0 = (y + y / 4 - y / 100 + y / 400 + t[month - 1] + day) % 7;

  return dow0 + 1;
}

bool rtcToEpoch(time_t &epochOut) {
  uint8_t sec, minu, hour, dow, dom, month;
  uint16_t year;

  if (!readDS3231Raw(sec, minu, hour, dow, dom, month, year)) {
    return false;
  }

  if (!rtcLooksSane(year, month, dom, hour, minu, sec)) {
    return false;
  }

  epochOut = utcToEpoch(year, month, dom, hour, minu, sec);
  return true;
}

// ============================================================
// GPS validity helpers
// ============================================================
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
void loop() {
  readGpsStream(false);

  servicePiUart();

  updateEventState();

  updateDisplay();

  serviceShutdownSequence();
  serviceHighPowerFailsafe();

  unsigned long now = millis();

  if (now - lastRtcCheck >= RTC_CHECK_INTERVAL_MS) {
    lastRtcCheck = now;
    compareRtcWithGpsAndCorrect();
  }
}

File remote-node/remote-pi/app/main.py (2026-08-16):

from __future__ import annotations

"""
BearWave remote-node main entry point
=====================================

WHAT THIS FILE DOES
-------------------
This file is the executable entry point for the Raspberry Pi remote-node
application.

It is intentionally small and focused. Most of the real logic lives in:

- esp_uart_client.py
- protocol.py
- js8_client.py
- pending_store.py
- remote_node_controller.py

This file is responsible for:

1. loading configuration
2. configuring logging
3. creating the main RemoteNodeController
4. running one complete wake-cycle transaction
5. returning a useful process exit code

WHY THIS FILE SHOULD STAY SMALL
-------------------------------
In BearWave, the controller logic is already complex enough. Keeping the entry
point clean makes the project easier to understand, test, and document.

This also makes deployment easier, because a systemd service or boot script can
simply run this file and rely on its process exit code.

EXPECTED EXECUTION MODEL
------------------------
This script is intended to be launched once per Pi wake cycle.

Typical lifecycle:
- ESP32 powers the Pi
- Linux boots
- this script starts
- it performs one full remote-node communications cycle
- the controller requests shutdown from the ESP32 when appropriate
- the process exits

PROCESS EXIT CODE POLICY
------------------------
The process returns an integer exit code so that:
- logs are easier to interpret
- systemd or shell wrappers can detect high-level outcomes
- future automation can distinguish major failure classes

Current exit codes:

    0   Success
        A message transaction completed successfully and the controller
        requested shutdown successfully.

    1   Controlled failure
        The controller ran, but the message was not acknowledged or another
        non-crashing operational failure occurred.

    2   Startup/configuration failure
        Something was wrong before the controller could run properly.

    3   Unexpected fatal exception
        The script encountered an exception outside the normal controller
        result path.

CONFIGURATION SOURCES
---------------------
This file currently supports configuration from environment variables.
That keeps it simple and avoids requiring an external configuration parser
at this stage.

If an environment variable is absent, a sensible default is used.

SUPPORTED ENVIRONMENT VARIABLES
-------------------------------
BEARWAVE_SERIAL_PORT
    Serial device path for the ESP32 UART link.
    Example: /dev/serial0

BEARWAVE_SERIAL_BAUDRATE
    UART baud rate for the ESP32 link.
    Example: 115200

BEARWAVE_JS8_HOST
    Hostname/IP for local JS8Call API.
    Example: 127.0.0.1

BEARWAVE_JS8_PORT
    Port for local JS8Call API.
    Example: 2442

BEARWAVE_CONTROL_CALLSIGN
    Callsign of the control node station.
    Example: G7PRW

BEARWAVE_NODE_ID
    Short internal BearWave node ID.
    Example: ND01

BEARWAVE_PENDING_STORE_PATH
    Filesystem path for the pending critical message JSON file.
    Example: /home/mark/bearwave/state/pending_message.json

BEARWAVE_ACK_WAIT_PER_ATTEMPT_S
    Seconds to wait for acknowledgement on each send attempt.
    Example: 45.0

BEARWAVE_MAX_SEND_ATTEMPTS
    Maximum number of send attempts per run.
    Example: 3

BEARWAVE_STARTUP_JS8_DRAIN
    Whether to drain stale directed JS8 messages on startup.
    Accepted true values:
        1, true, yes, on
    Accepted false values:
        0, false, no, off

BEARWAVE_ALLOW_COMBINED_ALARM_MESSAGE
    Whether TRAP+LOW_BAT should be sent as one combined critical message.
    Accepted values are the same as above.

BEARWAVE_LOG_LEVEL
    Python logging level.
    Example:
        DEBUG
        INFO
        WARNING
        ERROR

BEARWAVE_SSTV_ENABLED
    Enable the optional post-ACK SSTV image stage for trap alarm messages.
    Heartbeat and low-battery-only messages do not trigger SSTV.
    Defaults to false.

BEARWAVE_SSTV_DRY_RUN
    Log SSTV capture/encode/transmit commands without running them.
    Defaults to true for safe bench testing.

BEARWAVE_SSTV_WORK_DIR
    Directory for captured images and generated SSTV WAV files.

BEARWAVE_SSTV_MODE
    SSTV mode label passed to the encoder. Example: Robot36.

BEARWAVE_SSTV_REPEAT_COUNT
    Number of times to play/transmit the generated SSTV WAV.

BEARWAVE_SSTV_PREPARE_COMMAND
    Image preparation step. The default "__pillow__" uses built-in Pillow
    resizing and avoids an ImageMagick dependency.

BEARWAVE_SSTV_TRANSMIT_COMMAND
    Shell command used to transmit the generated SSTV WAV. In the deployed
    QDX setup this should key CAT PTT, play the WAV, then release PTT.

EXAMPLE USAGE
-------------
Manual execution from a virtual environment:

    source ~/bearwave/.venv/bin/activate
    python main.py

With overrides:

    BEARWAVE_NODE_ID=ND03 \
    BEARWAVE_CONTROL_CALLSIGN=G7PRW \
    python main.py
"""

import logging
import os
import sys
from dataclasses import asdict

from remote_node_controller import (
    ControllerRunResult,
    RemoteNodeConfig,
    RemoteNodeController,
    configure_default_logging,
)
from sstv_image import SstvImageConfig


# ============================================================================
# Exit-code constants
# ============================================================================
#
# These symbolic constants make the code easier to read than raw integers.
# ============================================================================

EXIT_SUCCESS = 0
EXIT_CONTROLLED_FAILURE = 1
EXIT_STARTUP_FAILURE = 2
EXIT_FATAL_EXCEPTION = 3


# ============================================================================
# Environment parsing helpers
# ============================================================================
#
# These helpers convert environment variables into the strongly typed values
# expected by RemoteNodeConfig.
# ============================================================================


def env_str(name: str, default: str) -> str:
    """
    Read a string environment variable, returning a default if unset.

    Whitespace is stripped from both the environment value and the default.
    """
    value = os.getenv(name)
    if value is None:
        return default.strip()
    return value.strip()


def env_int(name: str, default: int) -> int:
    """
    Read an integer environment variable.

    Raises:
        ValueError if the environment variable exists but is not a valid
        integer.

    WHY THIS RAISES
    ---------------
    Configuration errors should fail early and clearly rather than silently
    producing unexpected behavior later.
    """
    value = os.getenv(name)
    if value is None:
        return default

    try:
        return int(value.strip())
    except ValueError as exc:
        raise ValueError(
            f"Environment variable {name!r} must be an integer, got {value!r}."
        ) from exc
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

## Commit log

2026-07-27 Add BearWave PCB V2 latch power control
2026-08-02 Fix PCB V2 12V status polarity
    [BearWave_ESP32_Remote_Node_Supervisor.ino]
2026-08-09 Update remote node V2 power and JS8 startup flow
2026-08-10 Add remote node enclosure print files
    [BasePlate.3MF, BatteryClip.3MF, BatteryCover.3MF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]
2026-08-10 Display enclosure renders in hardware README files
2026-08-16 Wake ESP32 supervisor from trap inputs
